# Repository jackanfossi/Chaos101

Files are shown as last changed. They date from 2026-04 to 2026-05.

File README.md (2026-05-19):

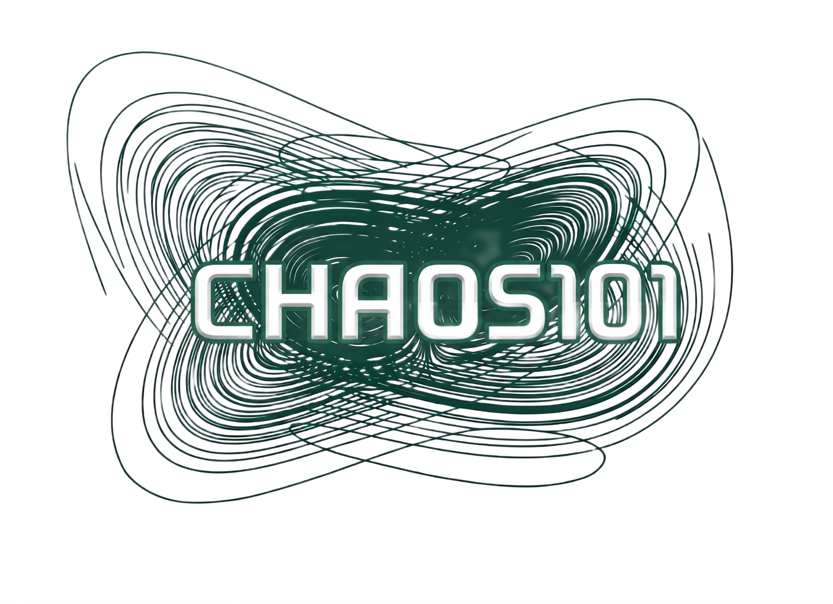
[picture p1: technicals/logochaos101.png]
#  Chaos 101

<p align="center">
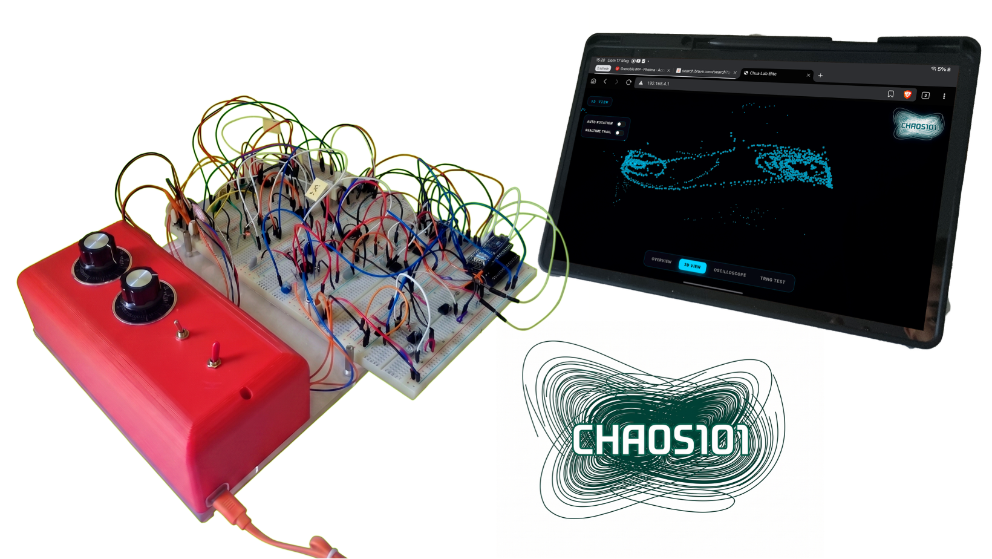
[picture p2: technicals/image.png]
Chaos 101 Ecosystem
  
</p>

Welcome to **Chaos 101**, an interactive project developed at **Grenoble INP - Phelma** to bridge the gap between abstract mathematics and physical reality.

We provide a tangible educational experience to explore how deterministic rules can lead to completely unpredictable behavior. Through our custom electronic circuit and Wi-Fi visualization system, you can discover the **"order hidden behind chaos"** and its vital role in modern technologies like secure data encryption.

---

## 🌀 Chaos for Everyone: An Intuitive Introduction
If you are new to this topic, here is a simple way to understand what we are working on:

### 1. Deterministic but Unpredictable
Usually, we think the world is either **predictable**, like planetary orbits, or **random**, like thermal fluctuations. Chaos is a special third category: it follows precise rules (it is deterministic), yet it turns out to be completely unpredictable over the long term.

### 2. The Butterfly Effect
The core of chaos is **extreme sensitivity to initial conditions**. If two identical chaotic systems start from states that differ by only a microscopic margin, their trajectories will eventually yield completely different outputs. This is why even a tiny change can lead to a massive difference later on.

### 3. Why is it useful? (TRNG)
Because chaos is so sensitive and unpredictable, it is perfect for creating **True Random Numbers**. While computers usually use predictable algorithms to create "random" numbers, our circuit uses the physical "messiness" of chaos to create sequences that are mathematically impossible to predict with precision. This makes digital encryption and cybersecurity much safer.

## 📂 Project Overview: What you will find
Based on our technical specifications, this repository provides a functional educational package that includes a real working device and the associated documentation. The goal is to provide an intuitive and visual comprehension of a chaotic system through an electronic circuit.

In this project, you will find:
* **Tangible Educational Device:** A portable and interactive hardware station designed for the general public.
* **Visualization System:** Direct monitoring of the system's evolution and display of the characteristic phase space diagrams, called attractors.
* **Wireless Communication:** A microcontroller interface using Wi-Fi protocol to allow for a simple setup and smartphone connection.
* **Practical Application (TRNG):** A demo of a True Random Number Generator to showcase the relevance of chaos theory in technology and security.
* **Autonomous Power Supply:** The entire system features an autonomous power supply to ensure maximum portability for events.
* **Open-Source Access:** Full technical documentation and a guide to set up the experience autonomously.
### Functional Diagram
<p align="center">
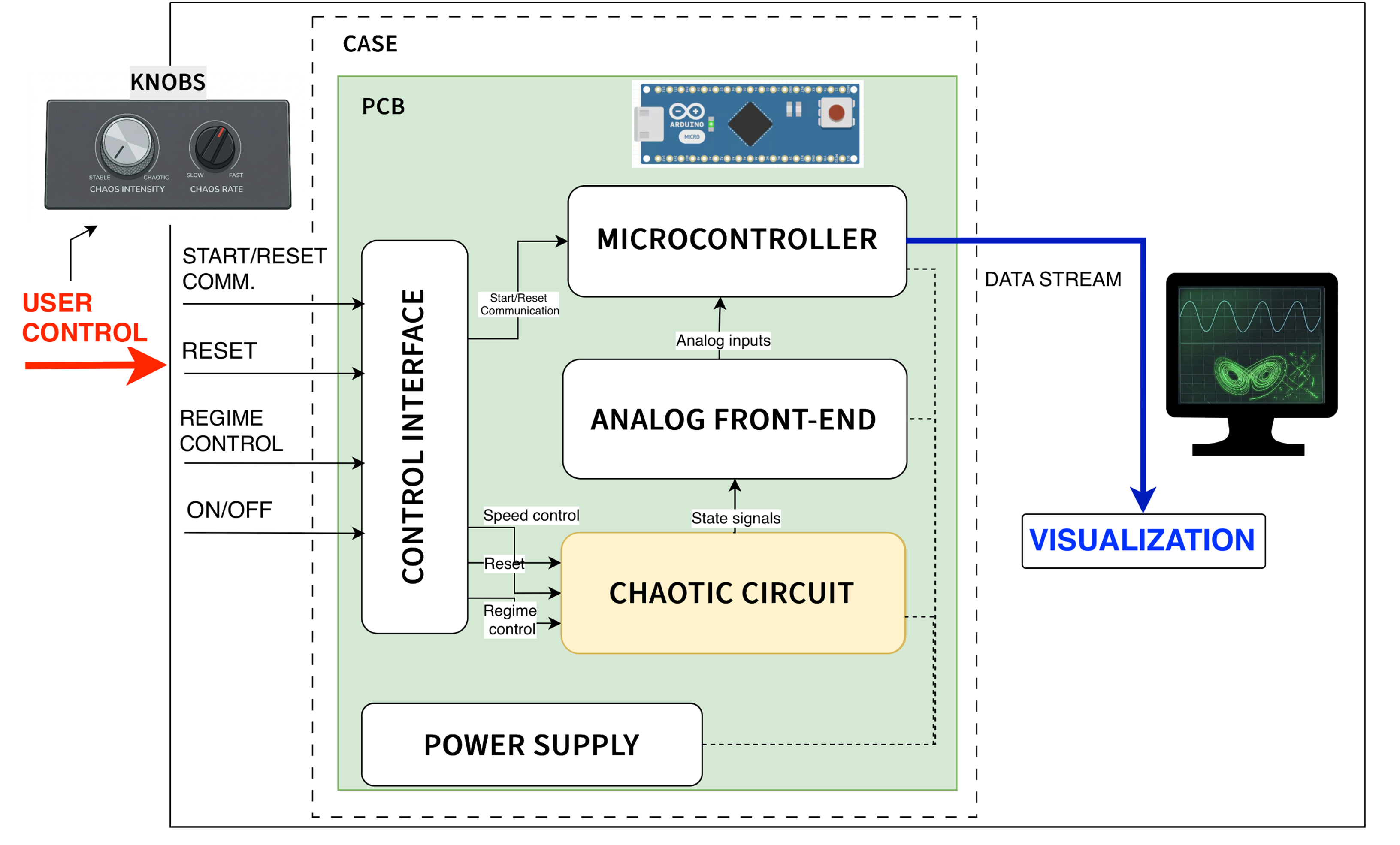
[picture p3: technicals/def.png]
Chaos 101 Functional Diagram
  
</p>

---

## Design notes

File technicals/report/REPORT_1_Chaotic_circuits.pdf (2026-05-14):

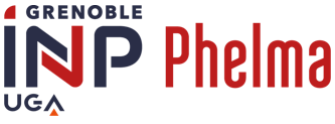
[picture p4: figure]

## Grenoble INP - Phelma MSc in Nanotechnologies Academic Year 2025 – 2026

# Chaos 101

## Project Phase 2: Specifications

## Team Members

Anfossi Giacomo | Jeljal Yanis
Bendin Andrea | Kovalchuk Anhelina
Fugnanesi Diana | Lanfranchi Tommaso
Gotas Matthieu | Tannenberg Finn

## Jalel Tasnim

## Tutors

## Prof. Davide Bucci Dr. Martial Defoort

May 14, 2026

Contents | Contents

# Contents

1 Excellence | 1
2 Impact | 5
3 Implementation | 7
References | 11

i

1. Excellence

# 1. Excellence

## 1.1. Objective

Introduction to chaos theory
It is common to think about the world as composed of two main types of systems. On the one hand, there are deterministic systems, such as a simple pendulum or planetary orbits. Their future states can be predicted with a high degree of accuracy once the governing laws and initial conditions are known. On the other hand, there are random systems, such as thermal fluctuations or the radioactive decay of an atom, which behave in an unpredictable manner and can only be described in terms of probability. Beyond these two main categories there is actually another class of systems whose evolution in time is perfectly described by some rules, meaning it is perfectly deterministic, yet turns out to be completely unpredictable over the long term: this is called chaos. This inherent unpredictability arises from the system’s extreme sensitivity to initial conditions. If two identical chaotic systems are initiated from states that differ by only a microscopic margin, their trajectories will eventually yield completely different outputs. This phenomenon is widely known as the butterfly effect, a concept first formally described by Edward Lorenz during his study of weather models in 1963 [1]. Since those foundational studies, chaos theory has developed over the decades. Researchers have identified and described chaotic dynamics in numerous natural and artificial systems, namely weather patterns, chemical reactions, lasers, fluid dynamics and electronic circuits [2]. Over time, chaos has also increasingly been studied with an engineering approach to be used for real-world technology. Several research fields are nowadays being explored, like cryptography and neuronal modeling [3, 4], but also concrete applications such as the True Random Number Generators (TRNGs) have emerged, making chaos theory a highly relevant field of study in contemporary technological research [5, 6] .

The electronic approach
In the context of chaos theory, electronic circuits are of huge interest. This branch of research has long explored the possibility of implementing chaotic behavior within electronic systems, starting with the pioneering work of Leon Chua [7]. The electrical domain is particularly advantageous because it provides a large degree of freedom for modelling differential equations and integrating non-linear components. Moreover, electronic circuits are robust, controllable, easily measurable, and characterized by a fast response time. For these reasons, chaotic circuits have been extensively studied and represent the main platform for investigating chaotic behaviour [8, 9].

The educational problem
Despite its prevalence in nature and engineering, chaos theory remains a challenging subject to comprehend and communicate, mainly due to the inherent difficulty in understanding and describing these complex, non-linear dynamics. Taught through abstract mathematical models, students and general audiences consistently struggle to visualize chaotic behavior and grasp its physical meaning. This significant educational gap leaves people largely unaware of what chaos is and how its principles apply to real applications and become useful.

Project objective
To address this significant educational gap, the absolute priority of this project is to build a tangible educational device easily understandable for the general public that aims to provide the answers of two fundamental questions: "What is chaos?" and "Why is it useful?" The project aims to provide an intuitive and visual comprehension of a chaotic system, through an electronic circuit exploiting its several advantages. The aim is to illustrate the fundamental properties of chaos and its behaviour, and to provide a direct demonstration of a concrete application. This device should be portable, affordable, interactive and the best alternative to traditional (and sometimes expensive) lab equipment.

Expected outcomes and target audience
The expected outcome of this project is to deliver a functional educational package that includes a real working device and the associated documentation. Moreover, it aims to reach a highly diverse audience. The primary intention is to engage people attending science fairs: non-experts, students, children, but also stimulate researchers. This educational package is also envisioned to be utilized in other educational channels, in particular high schools or universities, as a kit for laboratory activities. It might serve as an interesting lab project to spark curiosity or, even more, as a useful practical tool to study non-linear dynamical systems.

1. Excellence | 1.2. Concept

## 1.2. Concept

The project idea

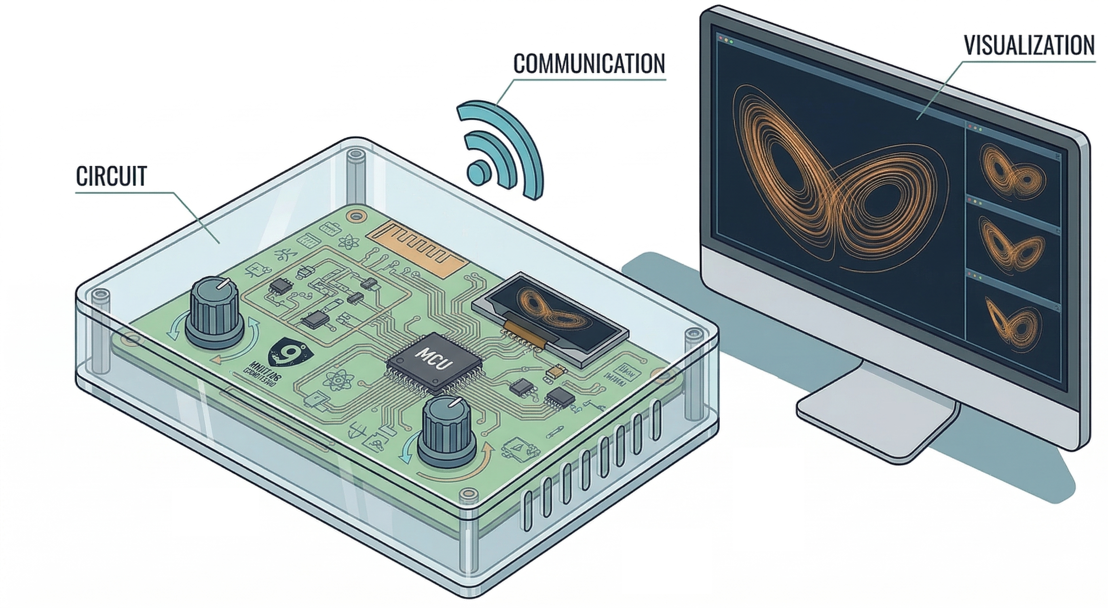
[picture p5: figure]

Figure 1: Project concept. Generated with AI Gemini

As presented, the goal of the project is to develop a device which will provide a laboratory experience related to chaotic systems. This device is based on a chaotic circuit, due to the numerous aforementioned advantages of working with electronics. Given its educational character, the name for this device and the entire project came naturally: CHAOS 101. The overall idea is to couple a visualization system to the chaotic circuit to display in real time its dynamical evolution and implement several features of interaction. The first question and the primary message to convey is “What is chaos?”. To tackle this, the main functions and features envisioned to be progressively implemented are:

1. Visualization system: direct monitoring of the system’s evolution and display of the characteristic phase space diagrams, called attractors. This is the most powerful aspect of the project, as it allows us to explain the order hidden behind chaos. It is envisioned to be developed through a microcontroller interface and wireless communication from the device to the visualization system. This allows for a simple setup procedure and opens the possibility of smartphone connection, which might be very useful for science fairs.
2. Transition from periodic dynamics to chaos: control over system parameters to transition from periodic to chaotic behavior. This allows for a hands-on experience where users can appreciate the transition and understand that it is something controllable and does not arise randomly.
3. Slowed-down evolution: system modifications to allow a slower evolution, demonstrating the phase space diagram formation and conveying a clear intuition of the unpredictable evolution.
4. Overlapping of trajectories: overlapping system trajectories with different initial conditions on the visualization, to show the sensitivity to initial conditions. This serves to convey the core concept of the definition of chaos.
5. Open-source access: an open-source repository to access all the useful material. The aim is to extend the project’s impact beyond the live presentation provided by the operator. This will include the full technical documentation and a guide to set up the experience, making CHAOS 101 accessible autonomously to everyone.

The second main question to address is "Why is it useful?" and for this the last feature to implement is:

6. Practical application: demo of a real application to transfer the relevance of chaos theory, in particular chaotic circuits, in technology and research.

Selection of the application
As previously mentioned, several research fields and concrete applications of chaos exist; thus, different options were analyzed to select the most suitable one. A significant technology in this context is the synchronization of multiple chaotic circuits. This phenomenon is the fundamental working principle of chaos-based encrypted communications, and it has also been widely studied as a physical model in biomedical engineering to simulate neuronal activity [10, 11, 12]. This is particularly relevant in medical research concerning Parkinson’s disease and the effects of Deep Brain Stimulation (DBS). However, the hardware implementation of synchronized circuits proved to be too elaborate within the scope of this project. Beyond the other applications, one revealed to be equally interesting and actually feasible: the True Random Number Generators.

1. Excellence | 1.3. Approach

Application: True Random Number Generator (TRNG)
TRNGs are a leading technology in the field of information security, where random number generation (RNG) is a key step to ensure high-security encryption. The TRNG represents the highest quality of RNG, performing over the widespread pseudo-RNG whose limitations are extensively known. The main feature of a TRNG is the coupling with a random physical process which guarantees a higher unpredictability. Common sources include thermal noise, phase jitter in oscillators, and also chaotic systems [6]. While the first two approaches are often affected by non-ideal circuit and environmental conditions, chaotic circuits are a perfect candidate for this application, leveraging on their nonperiodicity, broadband spectrum and their high sensitivity to initial conditions. The research is currently strongly focusing on optimizing chaotic TRNGs for ultra-compact, high-throughput hardware architectures, working on FPGAs and CMOS technologies [13]. Due to their superior energy efficiency, these modern chaotic generators are actively proposed for securing resource-constrained environments, such as Internet of Things (IoT) ecosystems, biomedical sensor networks, and edge computing devices[14].

## 1.3. Approach

Towards the technical implementation of the project several initial aspects need to be elaborated, in particular the feasibility assessment of hardware, TRNG implementation, communication plan and market analysis.

Feasibility assessment of hardware
A first investigation aims to select the most suitable chaotic circuit to implement. Specifically, the evaluation focuses on well-documented designs: the Chua’s circuit and its variants and the Sprott Jerk circuit [15, 16, 17]. The system of choice should balance manageable technical complexity with a high visual impact, allowing for the visualization and evolution of the "scenographic" shape of the attractor. The chaotic oscillators are evaluated based on their complexity, the availability of components in the university laboratory, and the shape of their phase space diagrams. Simulations are conducted using KiCAD and LTspice to gain familiarity before the physical implementation. This ensures that the chosen models are manageable and promising before moving to hardware implementation. After a comprehensive study of various chaotic oscillators, the selected circuits are tested in laboratory setup on the breadboard to validate the robustness of the design, the correct functioning, and reasonable controllability. Concerning the visualization the main interest is to develop a wireless communication between the hardware and the visualization. To this aim an interface using a microcontroller and Wifi protocol for the communication seems to be the most promising solution opening the possibility of smartphone connections. Initial testing is performed in the lab to assess its suitability.

TRNG implementation
To implement a reliable TRNG, the two main aspects to explore are the random number extraction and the validation tests. For the extraction, the main techniques that are considered are reported in Table 1. Concerning the validation, the methodology includes randomness and statistical testing. According to standards, the required validation test to be performed is the NIST suite [18]. However, in line with the pedagogical character of CHAOS 101, the testing is intended to be displayed in real-time. For this reason the full NIST is not feasible. Thus, alternative less formal tests have been identified, reported in Table 2.

A further idea is to show the superiority of the intrinsic entropy of hardware chaos with respect to the deterministic software algorithms used in pseudo-RNGs. To make this superiority tangible in terms of unpredictability and security, CHAOS 101 plans to showcase a side-by-side comparison between the circuit-generated sequence and a computergenerated one, highlighting how the proposed hardware system leverages sensitivity to initial conditions at a physical level so that even micro-environmental variations make the future sequence mathematically impossible to predict with precision, providing higher safety.

Extraction | Working Principle
ADC & LSB | Periodic sampling retaining only least signifi- cant bits [6].

Thresholding Analog comparison against a reference voltage
| to directly generate binary pulses [6].
Poincaré | Event-driven sampling triggered exclusively by specific state-space crossings [6].

Table 1: RNG strategies

Validation | Objective / Metric
Entropy | Evaluates information density [19].

χ

2
Test | Determines how much empirical distribution
| deviates from uniform [20].

Monte Carlo Spatial test mapping to (x, y); precision of
| π calculation depends on randomness qual-
| ity [20].
Table 2: Statistical tests for TRNG

1. Excellence | 1.4. Ambition

Communication plan
In order to showcase CHAOS 101 in a captivating and effective way, a communication plan will be developed. This will be designed for the audience to best experience chaos, considering not only what explanations to give, but also how to best convey them, for example, through direct interaction with CHAOS 101 or using a smartphone connection. To this end, a guide for the lab activity will be created, and these interactive aspects will be considered. In addition, other resources, such as posters to display during the events, may be produced. Furthermore, all documentation and materials will be carefully organized and shared through an open-source platform as a resource to autonomously develop the lab project.

Market Analysis
To validate the project’s assumptions regarding the general lack of awareness of chaos theory, an initial survey is going to be conducted targeting the general public, in particular students, and friends and relatives which still represents a good statistical set. The aim is to better solidify the relevance of the project.

## 1.4. Ambition

CHAOS 101 is not alone in the context of educational projects; there are already numerous useful resources available online. These have been analyzed, to identify where this project can bring significant improvements and distinguish itself from existing solutions.

Analysis of competitors
The most common methods to illustrate chaotic behavior can be broadly classified into two groups: purely digital simulations and purely physical systems. On the one hand, digital methods are simple to implement in classrooms and require little hardware, such as interactive simulations offered through websites or software tools like MATLAB or Python-based visualizations. They enable users to change system parameters and see the behavior that results in real time. These methods, however, don’t involve any real interaction. By using peripheral devices like a mouse or keyboard to abstract user input, the intuitive, physical understanding of the system is reduced.

On the other hand, physical demonstrations such as the Double Pendulum or a Magnetic Pendulum provide a direct, hands-on experience. These systems effectively illustrate sensitivity to initial conditions and are visually compelling. However, they are inherently limited in terms of controllability and parameter variation. Typically, the only form of interaction is the initial displacement, after which the system evolves autonomously.

Concerning electronic projects, several educational resources already exist covering all the different design circuits, Chua’s , Jerk’s, Lorentz’s to mention the most important. These contents provide documentation, tutorials, and video explanations, but these are generally self-contained in a website in the context of a "Do-It-Yourself" project and not widely available as a fully integrated, user-friendly educational device. They must be conducted in a lab setup, with costly instruments and they are not rapid and easy to assemble.

Envisaged innovation
CHAOS 101 aims to address all of these limitations. It aims to provide the double approach combining both physical interaction with dynamic parameter control. In contrast to purely mechanical systems, the circuit provides a way to adjust parameters, enabling transition from periodic to chaotic behavior.

In addition, compared to existing electronic projects, CHAOS 101 brings key innovations:

- Fully integrated physical interface, allowing for easy interaction with the circuit.
- Autonomous supply, making it a portable device
- Wireless data transmission system, allowing for simple setup and direct streaming of the state variables evolution into a web interface, eliminating the need for additional measurement tools such as an oscilloscope.
- Digital visualization opening numerous possibilities to share the resources with people rapidly and effectively.

Overall, it is worth noting that although the basic idea of an electronic chaotic circuit is not a new one, the contribution of this project lies in the integration of interactivity, accessibility, and modern connectivity. This makes the system particularly well-suited for educational and demonstrative purposes, where existing solutions either lack physical engagement or sufficient flexibility.

2. Impact

# 2. Impact

## 2.1. User Needs Analysis

To understand more precisely the impact and the relevance of CHAOS 101, a survey on chaos theory was shared with friends, students and relatives, who form a representative statistical set of the target audience. The goal was to assess the current level of awareness of the general public and bring foundation to this project. 93 answers were collected and the results are presented below.

## 2.2. Survey Results

The survey results reveal a generally limited familiarity with chaos theory.

Awareness and Knowledge Level

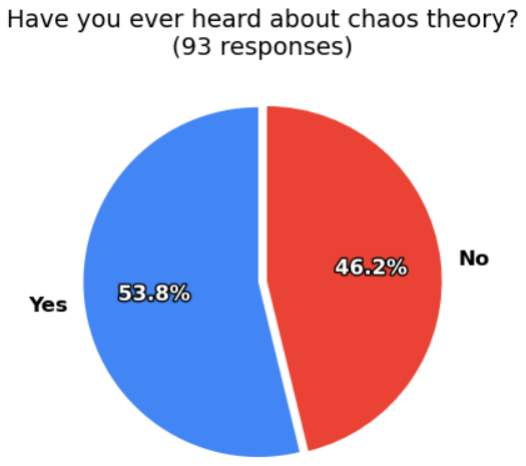
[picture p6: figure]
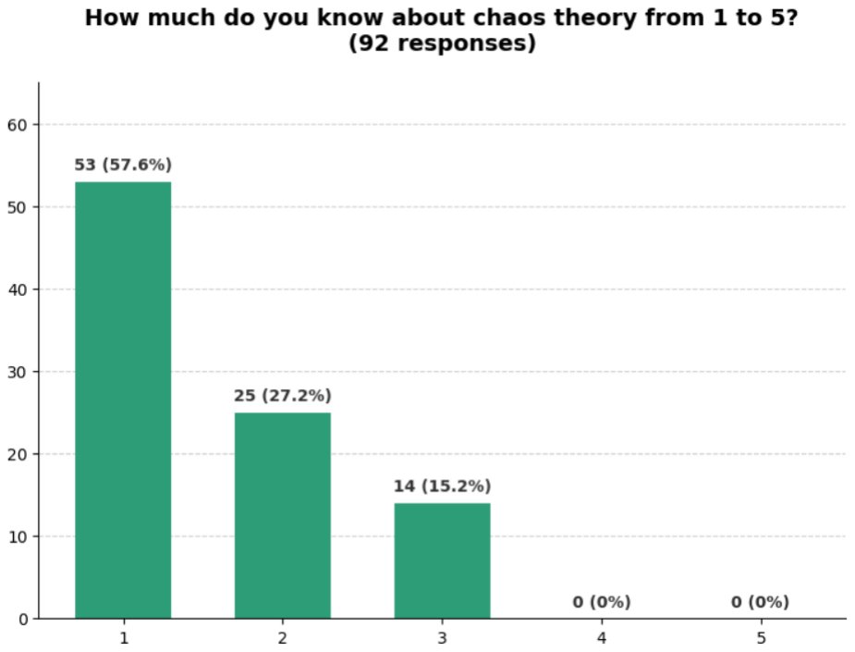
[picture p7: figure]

(a) Awareness of chaos theory | (b) Self-assessed knowledge level

Figure 2: General awareness and knowledge of chaos theory

As illustrated in Fig. 2a, more than half of the respondents (53.8%) reported having heard of chaos theory, while 46.2% had no prior exposure. However, awareness does not correspond to understanding. In fact, the majority of participants (57.6%) rated their knowledge at the lowest level (1 out of 5), while no respondents selected the highest levels, as shown in Fig. 2b. This shows that even among those who have heard of the term, the actual level of understanding is still very limited. This gap is likely due to the abstract nature of the topic, which is often introduced through mathematical formulations that are not easily accessible to a general audience.

Understanding and Perceived Applications

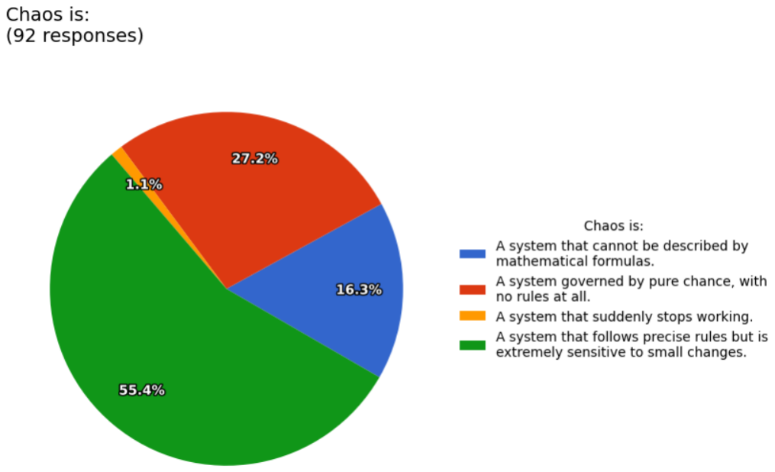
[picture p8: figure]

Figure 3: Definition of chaos

2. Impact | 2.3. Target Audience

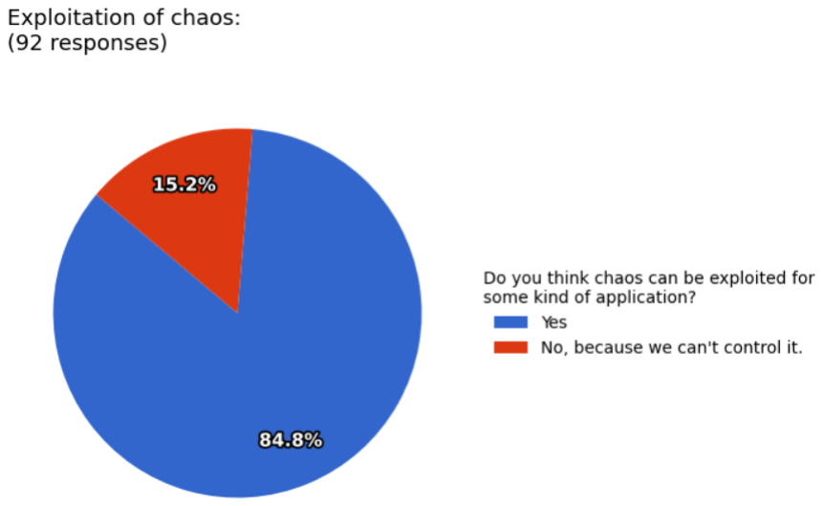
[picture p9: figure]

Figure 4: Perceived applications of chaos theory

As illustrated in the plot in Fig.3, when asked about the definition of chaos, only a portion of respondents correctly identified it as a deterministic system highly sensitive to initial conditions. A large number of participants instead associated chaos with randomness or unpredictability, highlighting several common misconceptions. Despite this limited understanding, a strong majority (84.8%) believe that chaos can have practical applications, as shown in the plot in Fig. 4. This suggests that people intuitively see that chaos is relevant in real-world phenomena, which could be used as a starting point for educational activities.

## 2.3. Target Audience

The project is designed for a broad and heterogeneous audience. Its primary target includes high school and undergraduate students, with limited exposure to advanced mathematical formalism, who can benefit from an intuitive and visual introduction to complex systems and chaos theory. Additionally, CHAOS 101 aims to reach a broader public of all ages, relying on the direct interaction, the visual impact and focusing the activity on a more basic level. The platform is also relevant for educators and science communicators, who may adopt it as a demonstrative tool to complement theoretical lessons with interactive experiences. Finally, CHAOS 101 also aims to stimulate researchers and highly qualified STEM professionals by showing concrete applications and highlighting the relevance of this research field.

## 2.4. Educational channels

Among the envisioned educational channels the main targets are science fairs and events; CHAOS 101 is intended as an assistive tool for researchers of this field to capture the attention of visitors and provide good communication. As already mentioned, this project is also intended to be used in schools and universities, as well as in museums and public exhibitions. Finally, internet is another relevant educational channel that will be utilized, particularly through an open-source platform, to reach the largest amount of people.

## 2.5. Market Positioning and Innovation Strategy

CHAOS 101 targets a growing niche market within the Educational Technology (EdTech) and science museum sectors. The main innovation is the shift from purely digital simulations to a tangible, hardware-based experience. While the physical implementation of the chaotic system is cost-effective and relatively simple, it offers clear advantages compared to existing software-based alternatives. For institutional users, such as schools and science festivals, the economic benefit is clear: a low-cost, durable device that provides a high-impact, "hands-on" learning experience. A key example of this added value is the integration of the Random Number Generator. By demonstrating a functional application in cybersecurity and data encryption, the exhibit is no longer just a visual demonstration, but also a practical proof-of-concept for real-world applications.

3. Implementation

# 3. Implementation

## 3.1. Project description

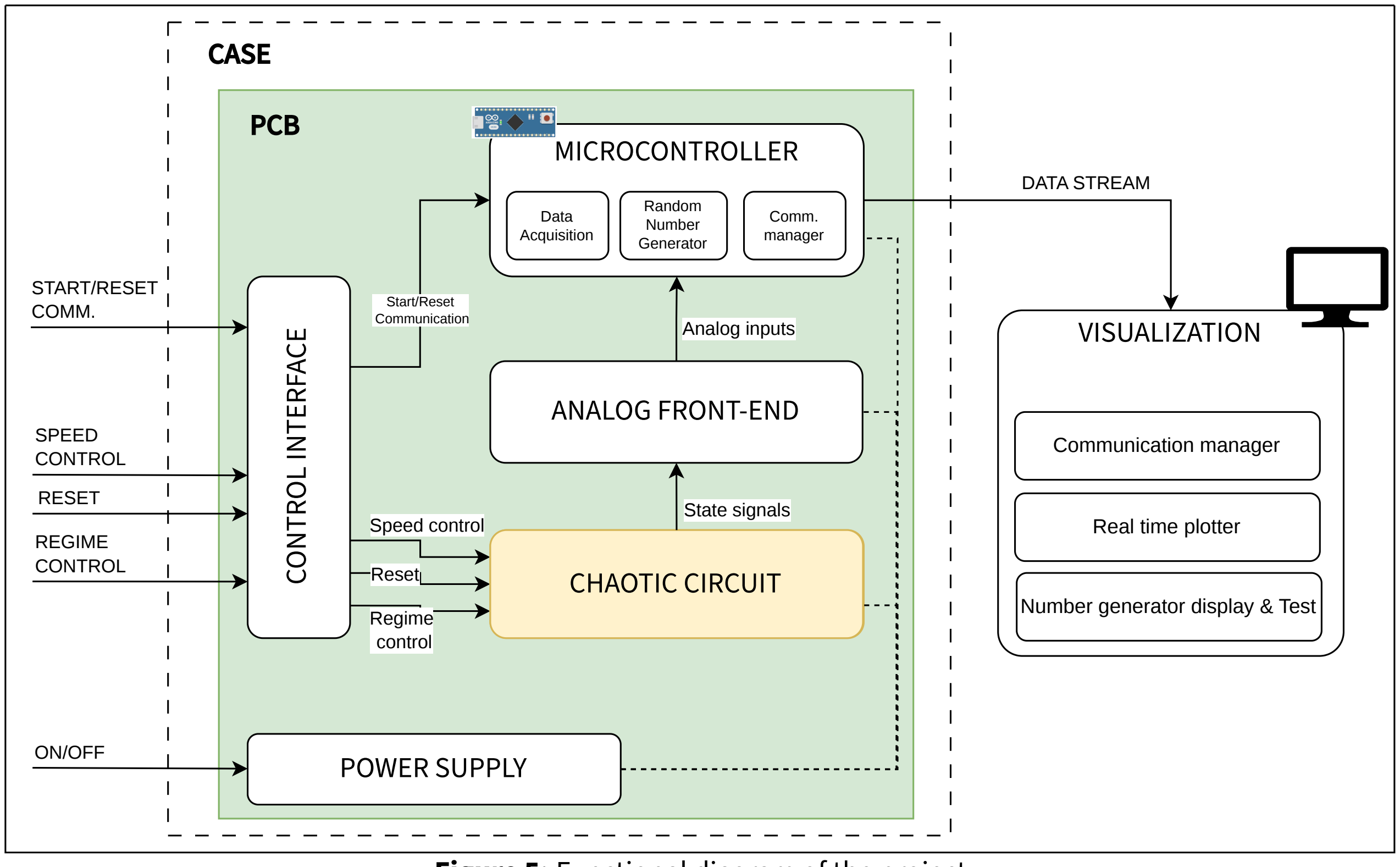
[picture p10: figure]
CASE; PCB PCB; Start/Reset Communication; Regime control; Reset; Speed control; POWER SUPPLY; MICROCONTROLLER; Data Acquisition; Random Number Generator; Comm. manager; CHAOTIC CIRCUIT; ANALOG FRONT-END; State signals; Analog inputs; REGIME CONTROL; RESET; SPEED CONTROL; VISUALIZATION; Communication manager; Real time plotter; Number generator display & Test; DATA STREAM; START/RESET COMM.; ON/OFF

Figure 5: Functional diagram of the project

A general description, shown in Figure 5, is presented regarding how the system is envisioned to be composed, along with the interaction of its main components. CHAOS 101 is composed of a hardware station that hosts the chaotic circuit and the electronic system to perform the readout. It features physical controls that allow the user to directly modify the circuit parameters and observe different dynamical regimes. The readout is handled with a microcontroller, which is properly interfaced to the circuit via an analog front-end. The microcontroller processes the acquired data, performs the random number generation and transmits everything to the visualization system using the most feasible communication protocol (unidirectional communication from micro to visualization). The visualization system then receives the data and produces the graphic display. The hardware station is implemented on a custom PCB and housed in a protective case. The entire system is also featured by an autonomous power supply to ensure maximum portability for the events.

## 3.2. Work packages definition

Based on the following structure, the development process is organized into distinct subtasks, referred to as Work Packages (WPs). The identified WP are presented in Table 3.

WP | Denomination
WP1 | Chaotic Circuit Development
WP2 | Analog Front End
WP3 | Firmware for Data Acquisition & Communication
WP4 | Visualization System
WP5 | Control functions
WP6 | Power Supply
WP7 | Random Number Generator
WP8 | PCB Design & Assembling
WP9 | Case Development
WP10 | Communication Plan & Branding

Table 3: List of Work Packages.

3. Implementation | | 3.3. Work packages description

## 3.3. Work packages description

The development process is structured into 10 distinct WPs, each with clearly defined objectives, deliverables and the team resources allocated.

- WP1: Chaotic Circuit Development Identification of the chaotic circuit to implement. It involves research in literature, identification of 3/4 circuits of interest followed by simulations using LTspice to study the dynamic and the setup parameters. Following these simulations, the breadboard implementation and physical validation are carried out.
Deliverable: Validated chaotic circuit schematic and assembled circuit onto the breadboard.
- WP2: Analog Front End Design, assembling and testing of the analog front end for output signal conditioning from the chaotic circuit to the microcontroller.
Deliverable: Circuit schematic and assembled circuit on the breadboard
- WP3: Firmware for Data Acquisition and Communication. Selection of an appropriate microcontroller, and firmware implementation, in particular reading of analog inputs, data processing, and real-time data streaming to the visualization system.
Deliverables: Firmware code
- WP4: Visualization System. Development of a local web interface designed to receive data from the microcontroller and plot the chaotic attractors in real-time, offering multiple visualization options for the audience. Deliverables: Web interface source code
- WP5: Control functions . Developing the user interface for physical interaction with the chaotic circuit. It includes integrating variable potentiometers, capacitors to slow down the signal, and control switches. Deliverables: updated circuit schematics integrating user controls and updated circuit on breadboard.
- WP6: Power Supply. This task is dedicated to designing an autonomous power supply system, including battery selection and the implementation of appropriate voltage converters for the microcontroller and operational amplifiers.
Deliverables: Power supply schematic, selected battery specifications and additional components.
- WP7: Random Number Generator. Theoretical development and practical implementation of the True Random Number Generator. Design of number extraction at the firmware/hardware level and display features on the visualization system.
Deliverables: updated microcontroller firmware/circuit schematic and updated web interface source code
- WP8: PCB Design & assembling. Transferring of the validated schematic circuit, fully tested on breadboard, into a permanent, robust PCB design. Assembling of the PCB and testing, design reiteration if needed. Deliverables: Fully printed, assembled, and functional PCB.
- WP9: Case Integration. Designing and manufacturing of the custom housing for the PCB to ensure safety, robustness portability, and a professional appearance.
Deliverables: Designed and 3D-printed enclosure.
- WP10: Communication Plan & Branding. Educational strategy, ensuring the final product effectively communicates chaos theory to the public. It includes defining the visitor experience and creating accessible documentation to share, identify a proper open source platform and share the material.
Deliverables: Support resources for CHAOS 101 and online upload of materials.
WP | Work Package Name | Responsible members
WP1 | Chaotic Circuit Development | Giacomo, Finn, Tasnim, Yanis, Matthieu, Diana, Tommaso
WP2 | Analog Front End | Matthieu, Tasnim
WP3 | Firmware | Anhelina
WP4 | Visualization System | Anhelina, Andrea
WP5 | Control functions | Yanis, Giacomo
WP6 | Power Supply | Finn
WP7 | Random Number Generator | Tommaso, Diana
WP8 | PCB Design & assembling | Yanis, Matthieu
WP9 | Case Integration | Andrea
WP10 | Communication Plan & Branding | Giacomo, Tommaso, Diana, Tasnim

Table 4: List of Work Packages.

3. Implementation | 3.4. Work timeline

## 3.4. Work timeline

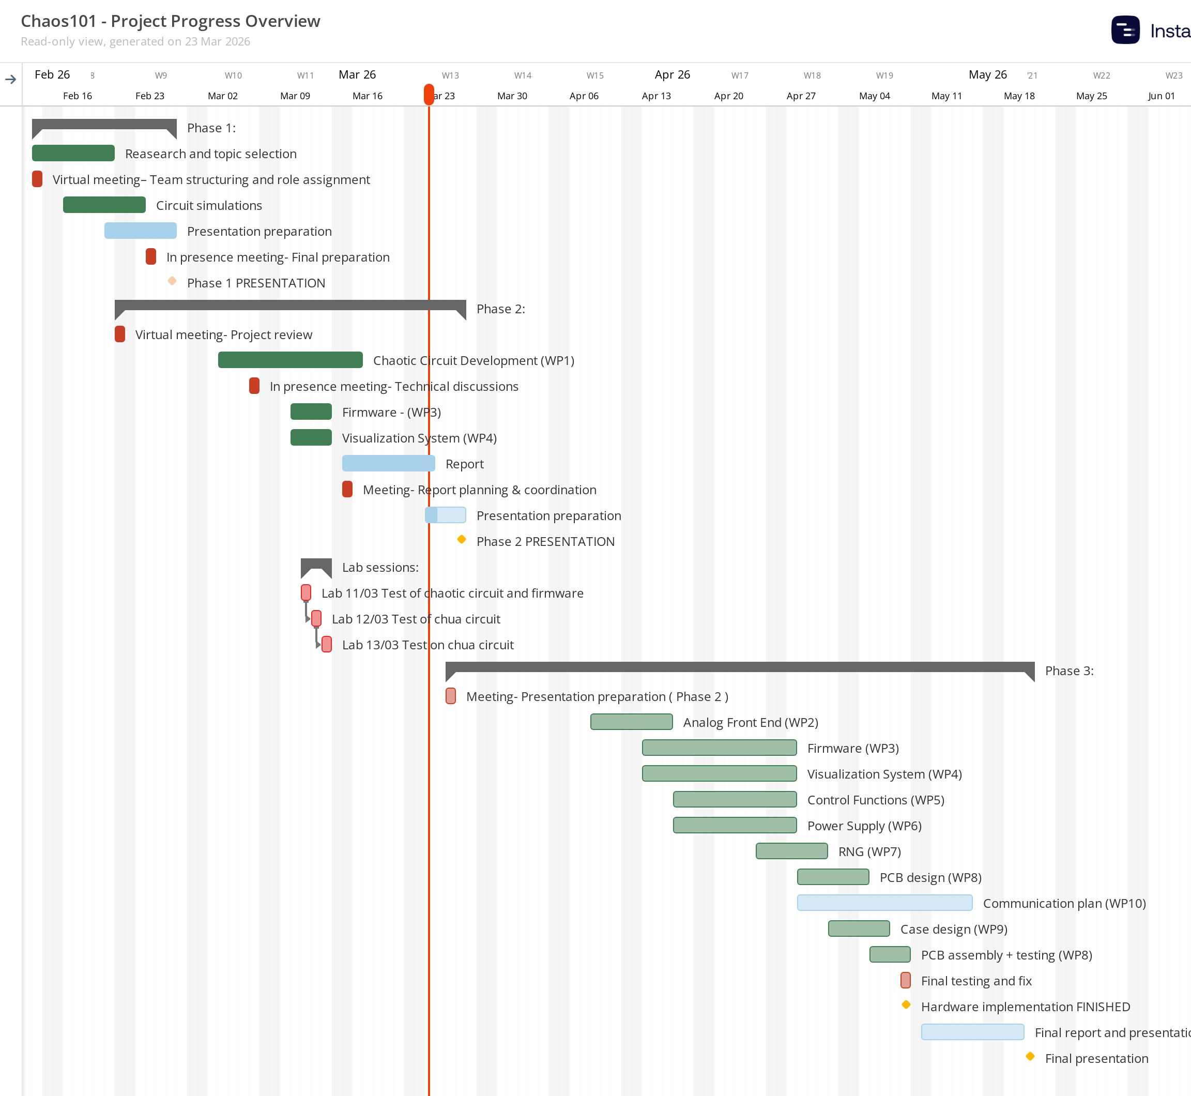
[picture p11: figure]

Figure 6: Gantt diagram of CHAOS 101 realized on Instagantt. Resource available online [21].

The project work is divided into three main phases: the preparation phase, the specification phase (currently ongoing), and the development phase. The key milestones that dictate the project’s evolution are the presentations scheduled for:

- PHASE 1: February 26 – State of the Art: Bibliographic study, physical principles, and context.
- PHASE 2: March 26 – Specifications: Building blocks, project scheduling, and market.
- PHASE 3: May 19 – Development: Technical achievements, final report, and discussion.

The work involves laboratory sessions, the scheduling of which is critical for progress. In Phase 2, laboratory sessions were carried out for the feasibility assessment and development of the chaotic circuit (WP1). In the upcoming development phase, the work packages have been allocated appropriate timeframes, and subsequent laboratory sessions will be scheduled for them. Work packages WP3 through WP6 will be carried out in parallel to maximize teamwork and efficiency.

Remark on Meetings Organization It is important to note that weekly meetings are not systematically planned in advance. Due to the collaborative nature of the project, frequent informal discussions take place among team members, with or without the tutor present, often during breaks or working sessions. Formal meetings are organized only when necessary, particularly at key stages of the project, such as for decision-making, progress evaluation, or the preparation of deliverables. This flexible approach allows the team to maximize the effectiveness of meetings.

3. Implementation | 3.5. Management structure and procedures

## 3.5. Management structure and procedures

The management structure of CHAOS 101is designed to be highly collaborative and agile. Rather than operating under a rigid hierarchy, for the crucial choices the team relies on a democratic decision-making process, thanks to the active contribution of each member. This structure ensures all team members are aligned and, more importantly, invested in the outcome. To ensure smooth progress, the specific decisions involved in the development are taken by the team members responsible of the work. For the internal communication, the team holds frequent coordination meetings, utilizing both in-person sessions and video conferencing.

While the team operates horizontally, one member actively assumes the role of a manager. This role involves maintaining an updated overview of the project, managing work divisions and internal communication, tracking task completion across different work packages, and ensuring that deadlines are met without overriding the democratic consensus of the group on last minute decisions. Furthermore, the team is split into 3 subdivisions: electronics, research, software as shown in Figure 7. This ensures clear subdivision of responsibilities; however, a strong flexibility is required to fulfil the various tasks, especially in light of project presentations, specifically, drafting reports, and conducting theoretical research.

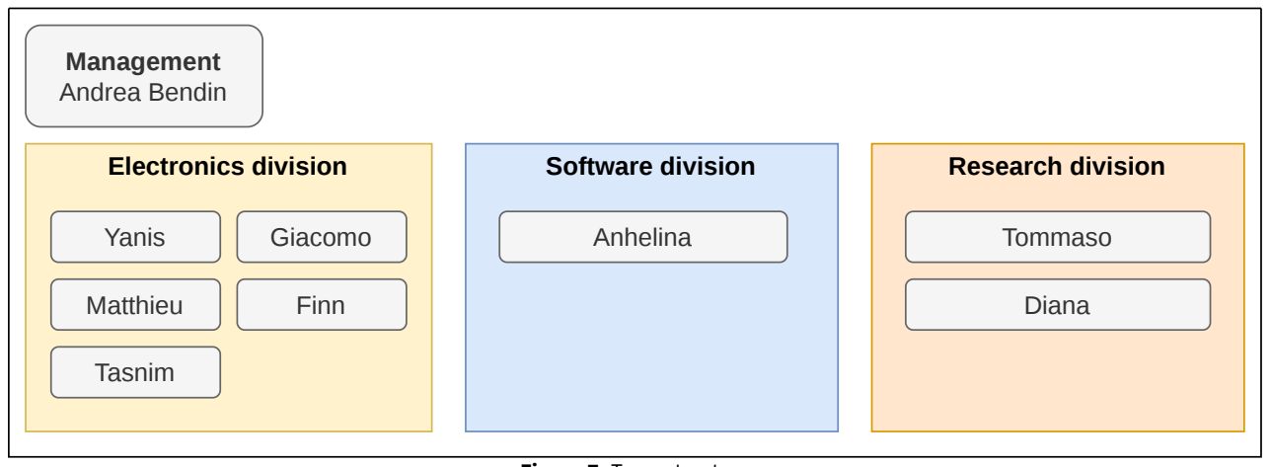
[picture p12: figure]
Yanis; Matthieu; Tasnim; Anhelina; Tommaso; Diana; Giacomo; Finn; Management Andrea Bendin

Electronics division | Software division | Research division

Figure 7: Team structure

## 3.6. Consortium as a whole

The consortium consists of nine dedicated members who possess a diverse and complementary skill set, allowing for an effective division of labor across specialized sub-groups while maintaining strong overall cohesion.

Yanis, Tasnim, and Matthieu possess relevant skills in PCB design and electronic assembly; therefore, they are responsible for the electronic development, supported by Giacomo, physics engineer, and Finn, electronic engineer, in the assembly and testing phases. Anhelina, biomedical engineer, having previous expertise in embedded system programming, is responsible for the firmware and the visualization system. Diana, physics engineer, and Tommaso, physicist, are in charge of the RNG implementation, leveraging their analytical and technical skills. Andrea, with experience in electronic and mechanical design, acts as the project manager, supervising the overall work of the subdivisions and designing the case.

Division | Member | Expertise

Electronic

| Jeljal Yanis | Electronics, PCB design
| Gotas Matthieu | Electronics, PCB design.
| Jalel Tasnim | Electronics, PCB design.
| Tannenberg Finn | Electronics, Optics
| Anfossi Giacomo | Physics, research analysis, electronics.
Research | Lanfranchi Tommaso | Theoretical physics
| Fugnanesi Diana | Physics, electronics.
Software | Kovalchuk Anhelina | Telecommunications, software development.
Management | Bendin Andrea | Electronics, mechanical design.

Table 5: Consortium members grouped by operational division and specialized expertise.

References | References

# References

[1] Edward N. Lorenz. “Deterministic nonperiodic flow”. In: Journal of the Atmospheric Sciences 20.2 (1963), pp. 130–141. DOI: 10.1175/1520-0469(1963)020<0130:DNF>2.0.CO;2. (https://doi.org/10.1175/1520-0469(1963)020<0130:DNF>2.0.CO;2)
[2] Steven H. Strogatz. Nonlinear Dynamics and Chaos: With Applications to Physics, Biology, Chemistry, and Engineering. 2nd ed. Boca Raton, FL: CRC Press, 2015. DOI: 10.1201/9780429492563. (https://doi.org/10.1201/9780429492563)
[3] Ljupčo Kocarev. “Chaos-based cryptography: a brief overview”. In: IEEE Circuits and Systems Magazine 1.3 (2001), pp. 6–21. DOI: 10.1109/7384.963463. (https://doi.org/10.1109/7384.963463)
[4] Kazuyuki Aihara, Teruya Takabe, and Masataka Toyoda. “Chaotic neural networks”. In: Physics Letters A 144.6-7 (1990), pp. 333–340. DOI: 10.1016/0375-9601(90)90136-C. (https://doi.org/10.1016/0375-9601(90)90136-C)
[5] Müştak E Yalçın, Johan AK Suykens, and Joos Vandewalle. “True random bit generation from a double-scroll attractor”. In: IEEE Transactions on Circuits and Systems I: Regular Papers 51.7 (2004), pp. 1395–1404. DOI: 10.1109/TCSI.2004.830683. (https://doi.org/10.1109/TCSI.2004.830683)
[6] Fei Yu et al. “A survey on true random number generators based on chaos”. In: Discrete Dynamics in Nature and Society 2019.1 (2019), p. 2545123. DOI: 10.1155/2019/2545123. (https://doi.org/10.1155/2019/2545123)
[7] Leon O Chua. “The genesis of Chua’s circuit”. In: AEU-Archiv für Elektronik und Übertragungstechnik 46.4 (1992), pp. 250–257.
[8] Jiří Petržela. “Chaos in Analog Electronic Circuits: Comprehensive Review, Solved Problems, Open Topics and Small Example”. In: Mathematics 10.22 (2022), p. 4381. DOI: 10.3390/math10224381. (https://doi.org/10.3390/math10224381)
[9] Leon O Chua. Chua’s Circuit: A Paradigm for Chaos. Singapore: World Scientific, 1993. DOI: 10.1142/2005. (https://doi.org/10.1142/2005)
[10] Louis M. Pecora and Thomas L. Carroll. “Synchronization in chaotic systems”. In: Physical Review Letters 64.8 (1990), pp. 821–824. DOI: 10.1103/PhysRevLett.64.821. (https://doi.org/10.1103/PhysRevLett.64.821)
[11] Stefano Boccaletti et al. “The control of chaos: theory and applications”. In: Physics reports 329.3 (2000), pp. 103–197. DOI: 10.1016/S0370-1573(99)00096-4. (https://doi.org/10.1016/S0370-1573(99)00096-4)
[12] James L. Hindmarsh and R. M. Rose. “A model of neuronal bursting using three coupled first order differential equations”. In: Proceedings of the Royal Society of London. Series B. Biological Sciences 221.1222 (1984), pp. 87–102. DOI: 10.1098/rspb.1984.0024. (https://doi.org/10.1098/rspb.1984.0024)
[13] Liang Yao, Peiyang Kang, Deqin Shi, et al. “IRCA-TRNG: A Lightweight Dual-Ring Chaotic TRNG With Perturbation Refresh for High Throughput”. In: IEEE Transactions on Very Large Scale Integration (VLSI) Systems 33.12 (2025), pp. 3329–3340.
[14] Min-Kyu Kim et al. “A 82-nW chaotic map true random number generator based on a sub-ranging SAR ADC”. In: IEEE Journal of Solid-State Circuits 52.7 (2017), pp. 1953–1965. DOI: 10.1109/JSSC.2017.2690875. (https://doi.org/10.1109/JSSC.2017.2690875)
[15] Davide Bucci. Playing with chaos - Le circuit de Chua. 2016. URL: http://davbucci.chez-alice.fr/index.php?argument=elettronica/chua/chua.inc (http://davbucci.chez-alice.fr/index.php?argument=elettronica/chua/chua.inc) (visited on 03/24/2026).
[16] Arturo Buscarino et al. A Concise Guide to Chaotic Electronic Circuits. Springer International Publishing, 2014. DOI: 10.1007/978-3-319-05900-6. (https://doi.org/10.1007/978-3-319-05900-6) URL: https://link.springer.com/book/10.1007/978-3-319-05900-6. (https://link.springer.com/book/10.1007/978-3-319-05900-6)
[17] ChuaCircuits.com. How to Build Chua’s Circuit. 2023. URL: https://chuacircuits.com/how-to-buildchuas-circuit-1/ (https://chuacircuits.com/how-to-build-chuas-circuit-1/) (visited on 03/24/2026).
[18] Andrew Rukhin et al. A statistical test suite for random and pseudorandom number generators for cryptographic applications. Tech. rep. Gaithersburg, MD, USA: National Institute of Standards and Technology (NIST), 2010. DOI: 10.6028/NIST.SP.800-22r1a. (https://doi.org/10.6028/NIST.SP.800-22r1a)
[19] Claude E Shannon. “A mathematical theory of communication”. In: The Bell System Technical Journal 27.3 (1948), pp. 379–423. DOI: 10.1002/j.1538-7305.1948.tb01338.x. (https://doi.org/10.1002/j.1538-7305.1948.tb01338.x)
[20] Athanasios Papoulis and S. Unnikrishna Pillai. Probability, Random Variables, and Stochastic Processes. 4th ed. McGraw-Hill, 2002.
[21] Instagantt. Project Schedule - Shared Gantt Chart. 2026. URL: https://app.instagantt.com/shared/s/D4HnvHKLigN9Yy3oHeY3/latest (https://app.instagantt.com/shared/s/D4HnvHKLigN9Yy3oHeY3/latest) (visited on 03/23/2026).

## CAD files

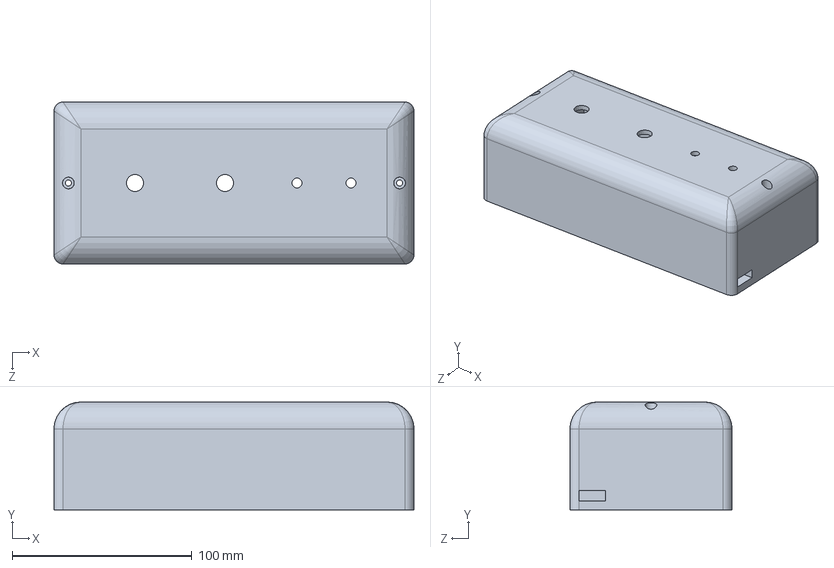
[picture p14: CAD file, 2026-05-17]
technicals/Chaos101_tech/Case.SLDPRT
200.0 x 60.0 x 90.0 mm

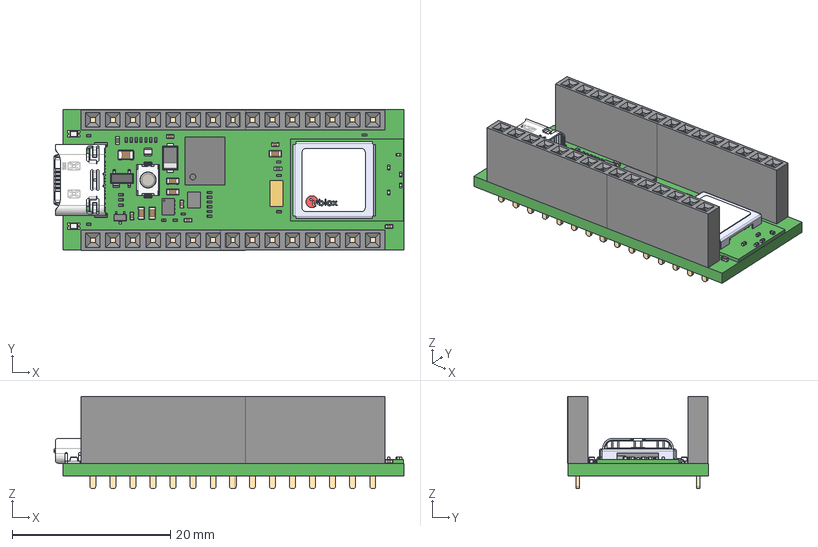
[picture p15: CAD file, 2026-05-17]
technicals/Chaos101_v14/Librairies/03-Modeles3D/NANO_ESP32.step
44.3 x 17.8 x 11.7 mm
RES-0201 x 21
CAP-0402 x 6
Extruded x 90
CAP-0201 x 4
pins
logo
label_8x8
logo_x_4mm
logo_o_4mm
logo_l_4mm
logo_b_4mm
logo_u_4mm
MAYA_W1_Shield_UBXH04-0000683
RES-0402 x 2
Thermal_Shape
SOT-523
HSMx-190 x 2
CAP-0603 x 5
lead x 2
SMLP34RGB
Header _Fem_1X8 x 4
PTS820J20KSMTRLFS
CX90B-16P_3D
PRTR5V0U2X
CAP-0805

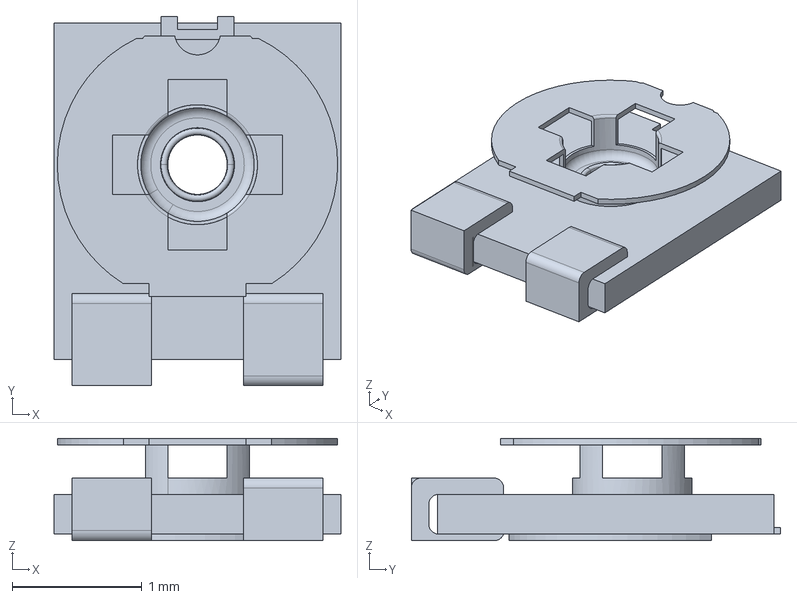
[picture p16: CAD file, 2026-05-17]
technicals/Chaos101_v14/Librairies/03-Modeles3D/TC42.stp
2.21 x 2.84 x 0.787 mm

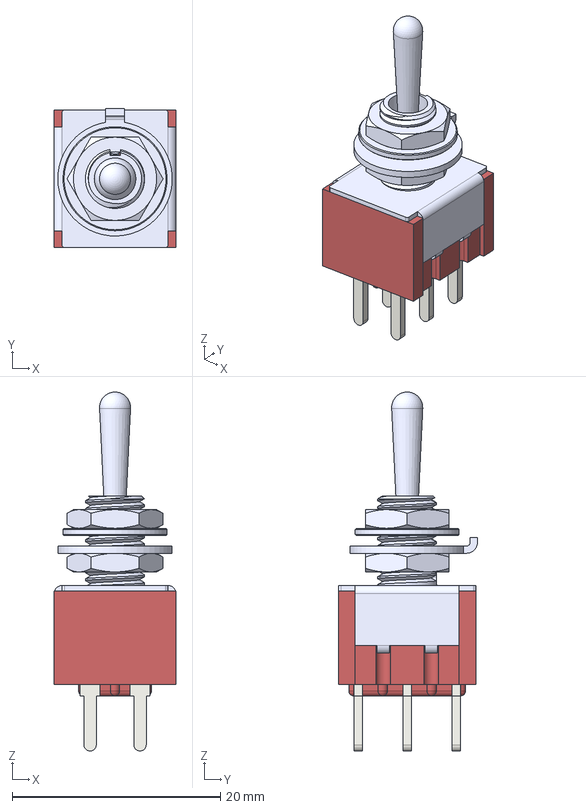
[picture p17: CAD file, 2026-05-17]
technicals/Chaos101_tech/Toggle_Switch_DPDT_PCB.step
11.7 x 13.4 x 34.5 mm
Washer Anti Twist Protection
Nut M6x0.75mm
Nut M6x0.75mm clone
Fantastic Plastic Body
Neck
Washer
PCB PIN 01
PCB PIN clone 02
PCB PIN clone 03
PCB PIN clone 04
PCB PIN clone 05
PCB PIN clone 06
Sheetmatal Frame
Font O 001
Font N 001
Font - 001
Font O 002
Font F 001
Font F 002
Font - 002
Font O 003
Font N 002
Batton

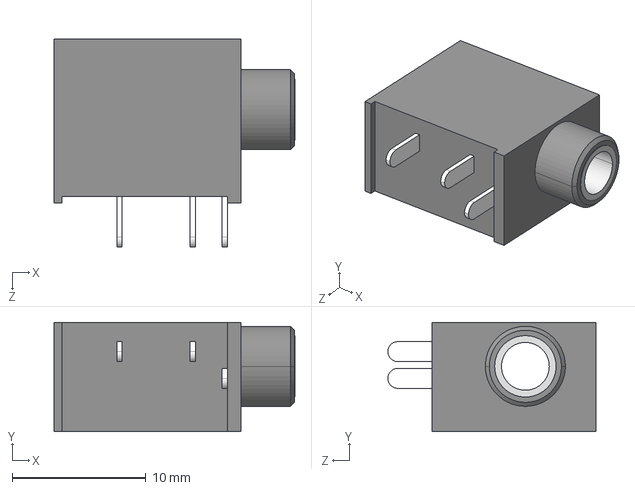
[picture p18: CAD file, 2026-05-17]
technicals/Chaos101_v14/Librairies/03-Modeles3D/CUI_DEVICES_SJ1-3533NG.step
18.1 x 8.20 x 15.6 mm

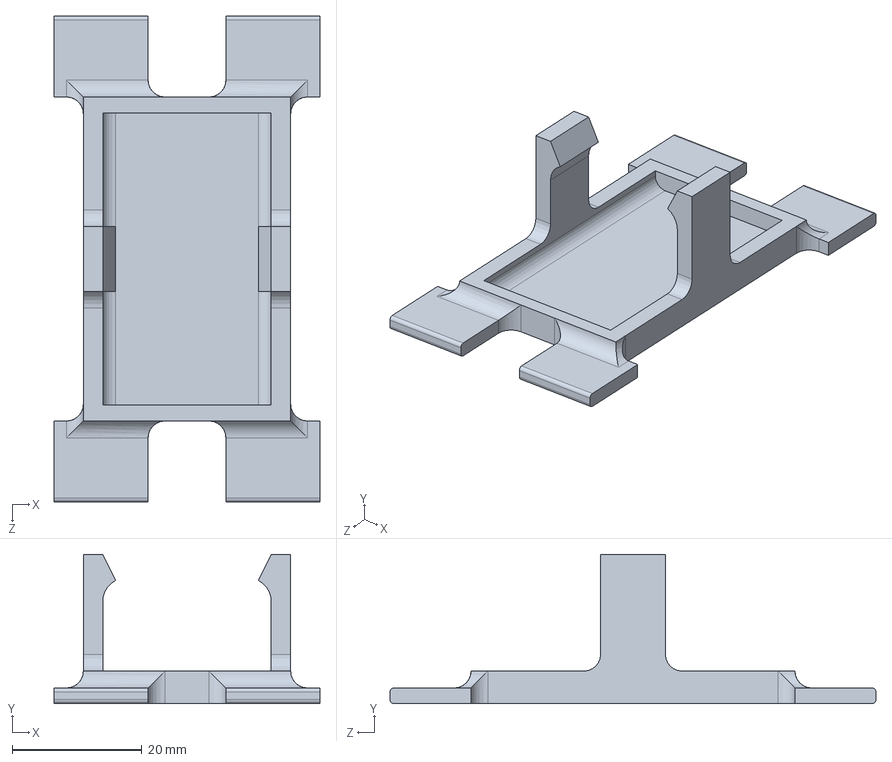
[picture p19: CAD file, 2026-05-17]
technicals/Chaos101_tech/Battery_Holder.SLDPRT
41.0 x 23.0 x 75.0 mm

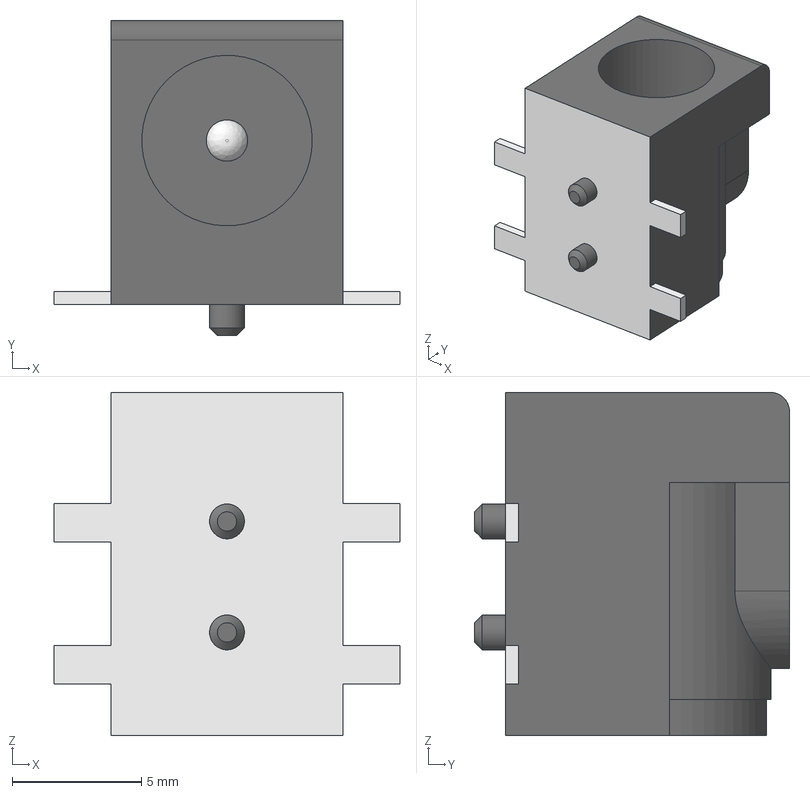
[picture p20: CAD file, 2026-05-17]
technicals/Chaos101_v14/Librairies/03-Modeles3D/BarrelJackSMD v3.step
13.4 x 12.2 x 13.3 mm

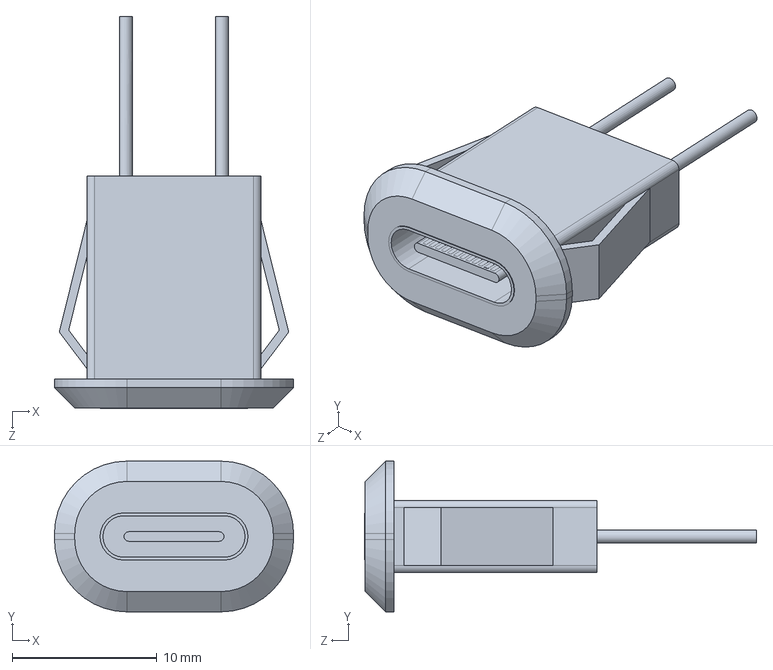
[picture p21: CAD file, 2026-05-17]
technicals/Chaos101_tech/USB-Port.SLDPRT
16.5 x 10.4 x 27.1 mm

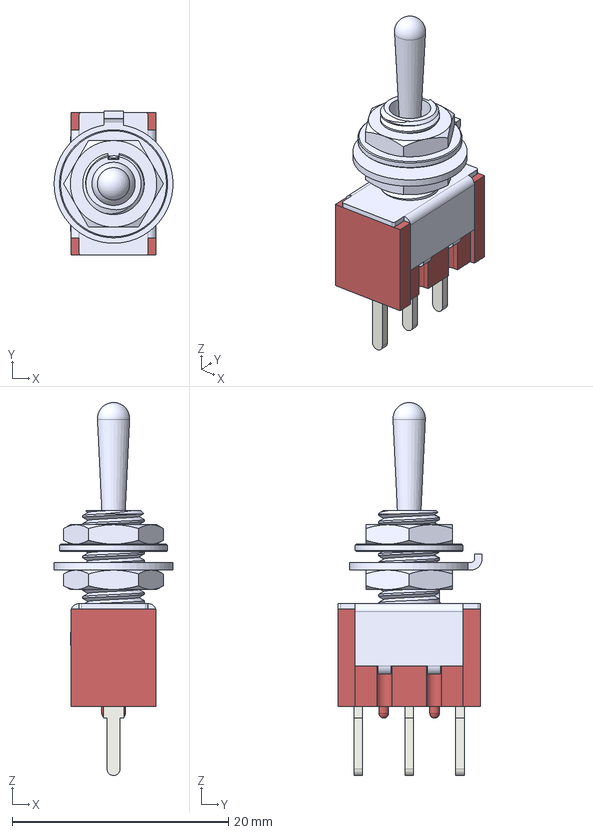
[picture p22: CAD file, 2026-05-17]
technicals/Chaos101_tech/Toggle_Switch_SPDT_PCB.step
11.0 x 13.4 x 34.5 mm
Washer Anti Twist Protection001
Nut M6x0.75mm 001
Nut M6x0.75mm clone001
Fantastic Plastic Body001
Neck001
Washer001
PCB PIN 002
PCB PIN clone 007
PCB PIN clone 008
Sheetmatal Frame001
Font O 004
Font N 003
Font - 003
Font O 005
Font F 003
Font F 004
Font - 004
Font O 006
Font N 004
Batton001

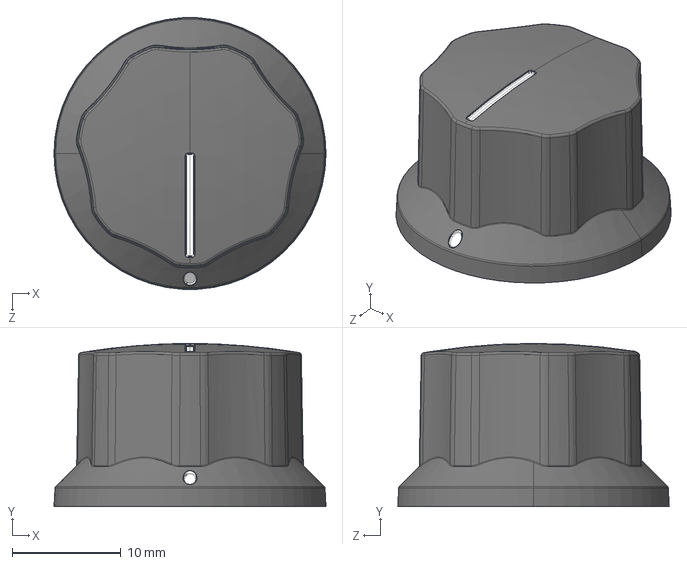
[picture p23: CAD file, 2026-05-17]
technicals/Chaos101_tech/MXR_ECB130_KNOB.STEP
25.0 x 15.0 x 25.0 mm

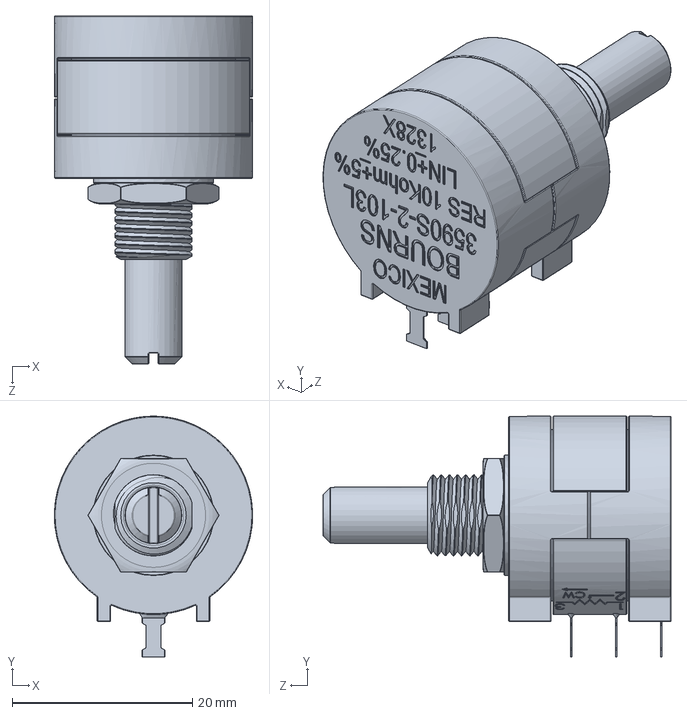
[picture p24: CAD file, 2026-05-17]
technicals/Chaos101_tech/multi turn.SLDPRT
22.0 x 26.7 x 38.6 mm

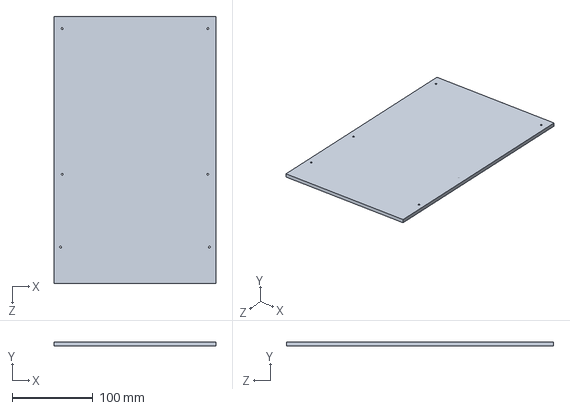
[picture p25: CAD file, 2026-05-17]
technicals/Chaos101_tech/Plate.SLDPRT
200.0 x 5.00 x 330.0 mm

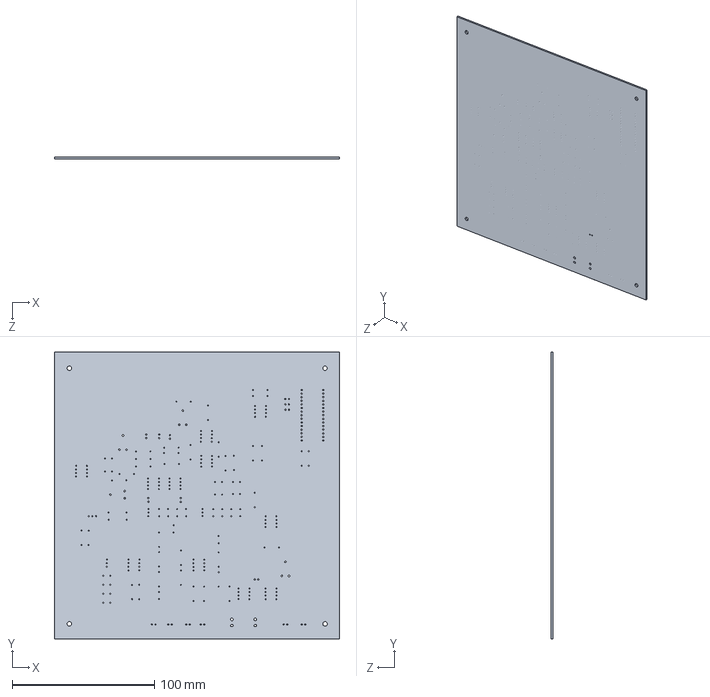
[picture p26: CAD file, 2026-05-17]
technicals/Chaos101_tech/PCB.SLDPRT
200.7 x 201.9 x 1.51 mm

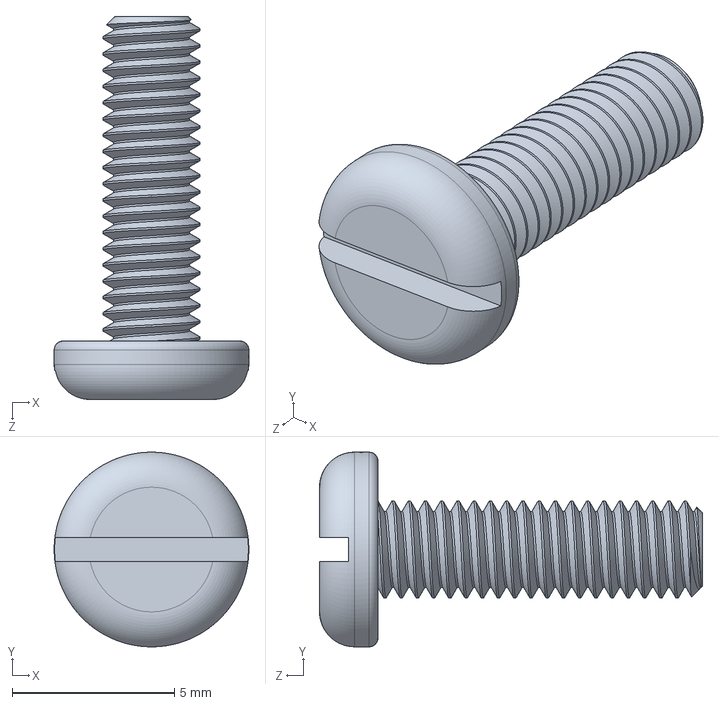
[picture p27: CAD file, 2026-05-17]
technicals/Chaos101_tech/91200A116_18-8 Stainless Steel Pan Head Slotted Screws.SLDPRT
6.00 x 6.00 x 11.8 mm

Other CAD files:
technicals/Chaos101_tech/Chaos101.SLDASM
technicals/Chaos101_tech/91920A570_Female Threaded Hex Standoff.SLDPRT
technicals/Chaos101_tech/94868A722_Female Threaded Hex Standoff(1).SLDPRT
technicals/Chaos101_tech/9v Duracell Battery Wyatt Sanders.ipt

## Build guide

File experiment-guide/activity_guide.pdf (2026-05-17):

CHAOS 101 — Activity Guide | Grenoble INP-Phelma · MSc Nanotechnologies

# CHAOS 101

## Activity Guide

G. Anfossi, A. Bendin, D. Fugnanesi, M. Gotas, T. Jalel, Y. Jeljal, A.
| Kovalchuk, T. Lanfranchi, F. Tannenberg

## 1. Introduction to Chaos

### What is chaos?

Chaos bridges the gap between order and randomness. It is deterministic yet unpredictable: while it follows exact mathematical laws, its long-term behavior remains impossible to forecast.

It is not randomness — it is extreme sensitivity to initial conditions.

### Applications and Importance of Chaos

Why study chaos?

- Understanding Natural Systems: From weather forecasting to stock market dynamics.
- Cryptography and Security: Utilizing extreme sensitivity to initial conditions to generate secure keys.
- Biomedical Engineering: Analyzing cardiac rhythms and brain activity patterns.

In our circuit, chaos enables TRNG by leveraging physical unpredictability over predictable algorithms. This ensures mathematically unpredictable sequences, greatly enhancing digital encryption and cybersecurity.

### The Chua’s circuit

This specific circuit was selected because it offers the simplest and most effective way to easily integrate and modulate complex chaotic behaviors in hardware..

Why Chua’s circuit?

- Simplest system for real chaos
- Fully op-amp based (TL082)
- Iconic double-scroll attractor

## 2. The Device Interface

### The Hardware

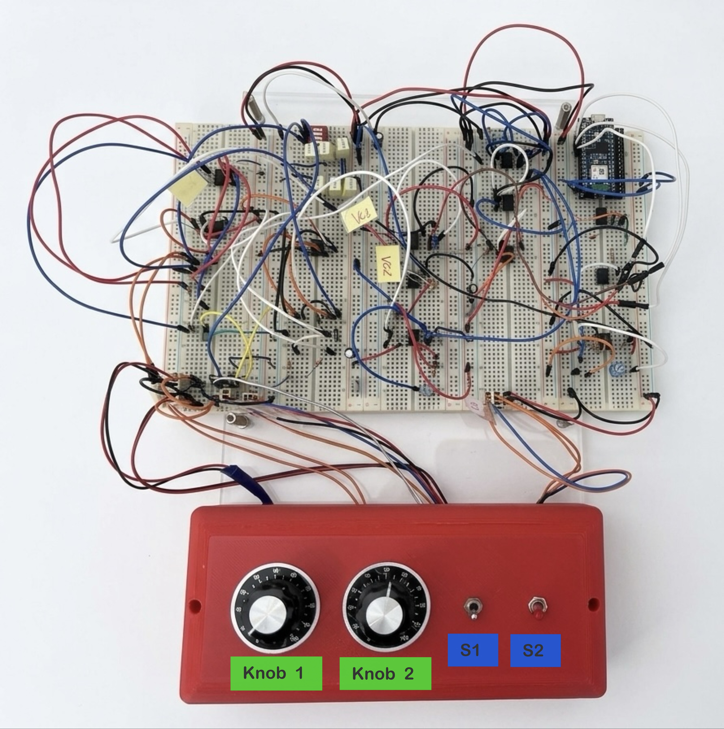
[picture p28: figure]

Figure 1: CHAOS 101 hardware station.

### Control Interface

- Knobs 1 & 2: Potentiometers to vary resistance and modify the output.
- Switch 1: Master switch for the dual 9V battery supply.
- Switch 2: Activates the ESP32 for 10 kHz sampling.

## 3. Activity: The First Flight

### How to power the sistem?

1. Connect the hardware via the USB-C input.
2. Toggle Switch 1 to power the circuit via batteries.
3. Toggle Switch 2 to power the ESP32 and enable the 5V data link.

1 · github.com/jackanfossi/Chaos101

CHAOS 101 — Activity Guide | Grenoble INP-Phelma · MSc Nanotechnologies

## 4. Web interface

Thanks to the onboard Wi-Fi powered by the Arduino-compatible ESP32, the CHAOS 101 interface is now live and accessible to everyone. Simply connect your own device to our web portal to explore the ’order within disorder’ in real-time.

### 3D phase space

1. Turn Knob 2 three full rotations to set the system’s equilibrium point.
2. Observe the periodic regime, which appears on the display as a stable elliptical trajectory.
3. Slowly rotate Knob 1 until the trajectories begin to intersect and diverge.
4. Continue adjusting until the Double-Scroll attractor forms—you have now generated real chaos.

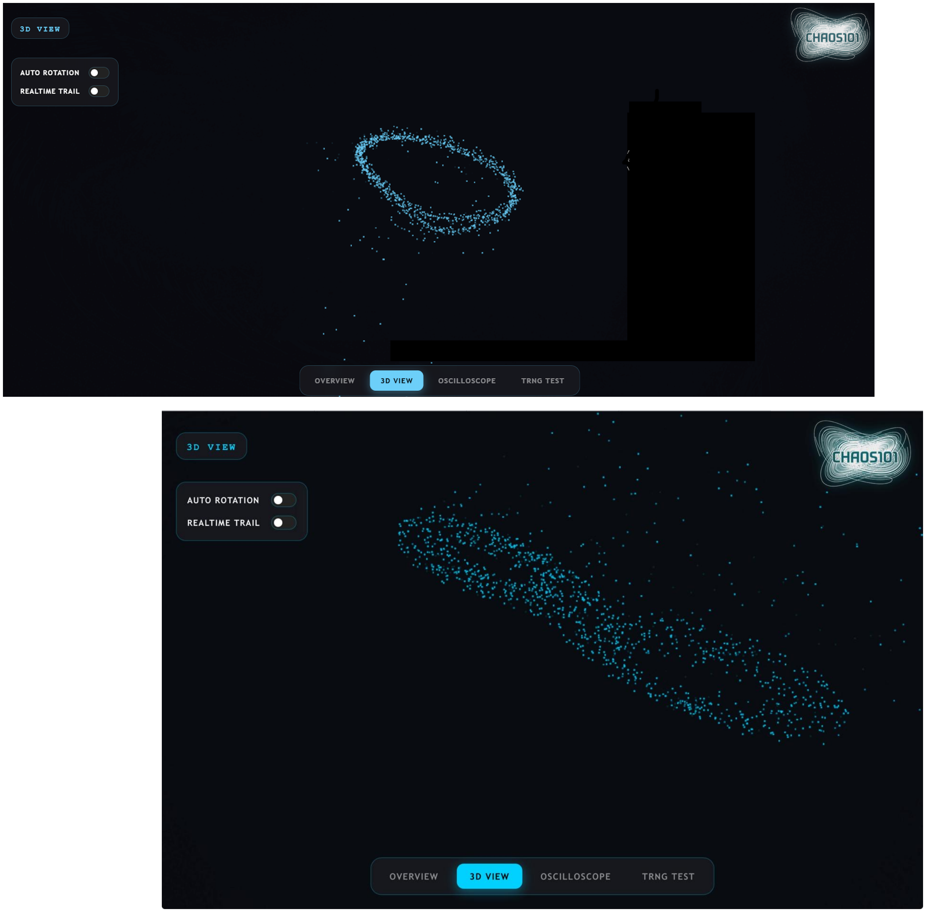
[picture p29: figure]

### Live oscilloscope

1. Real-Time State Monitoring: Monitor the circuit’s core state variables (V1, V2, and IL) directly in the time domain.
2. Chaotic Fluctuations: Witness unpredictable signals that never repeat the same pattern, illustrating the system’s extreme sensitivity.

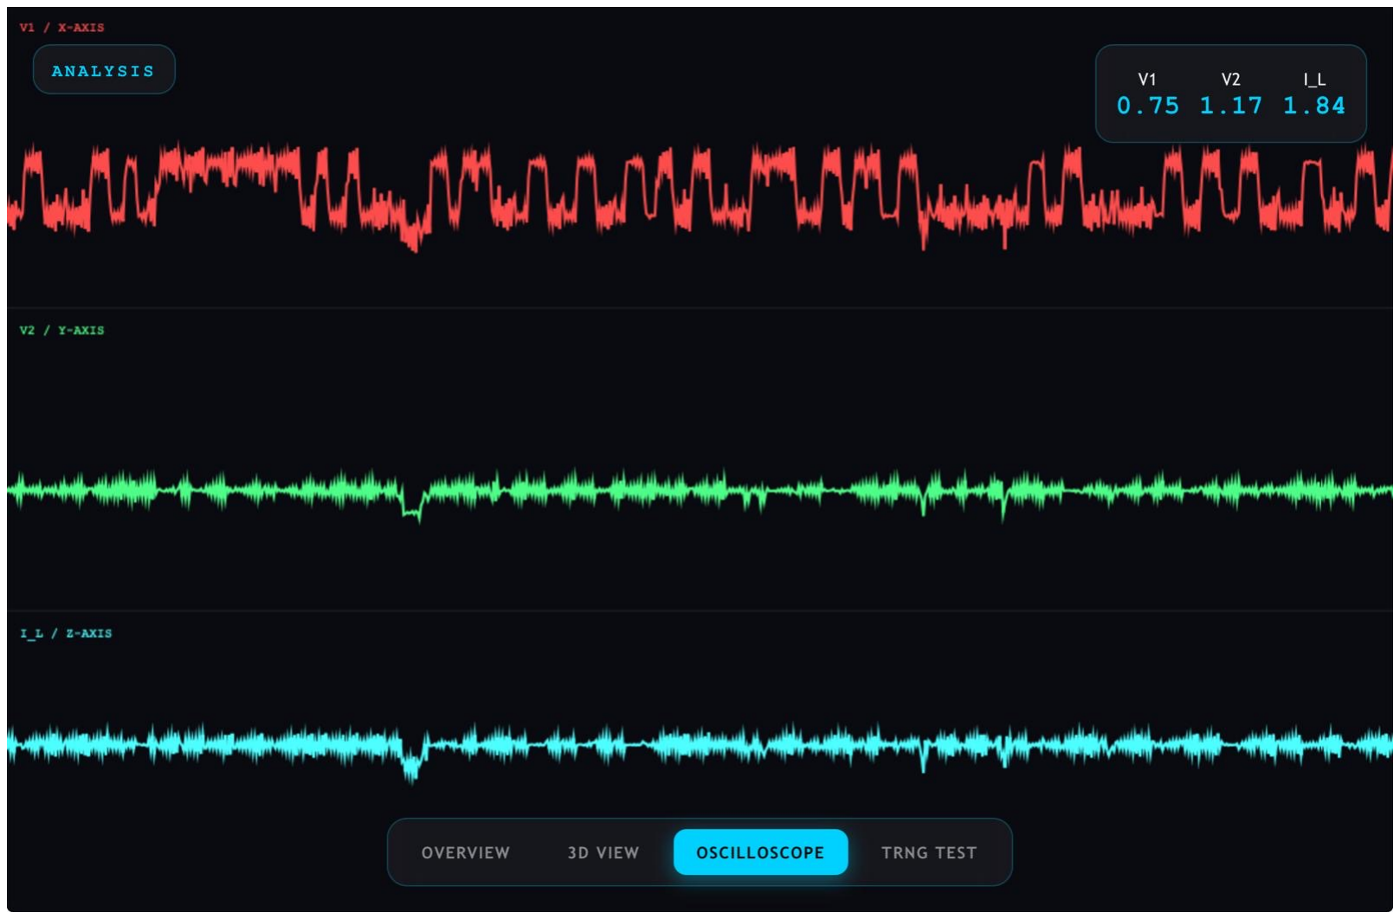
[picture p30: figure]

### TRNG

1. Analyze the TRNG Plots: Observe and interpret the generated visual plots to understand the source behavior.
2. Monte Carlo Plot: Verify the geometric randomness via the π estimation (3.168223), checking that the error remains below 1%.
3. Bitmap & Entropy: Analyze the spatial independence on the Noise Bitmap and verify that the entropy is near the ideal maximum (7.998205 bits/byte).

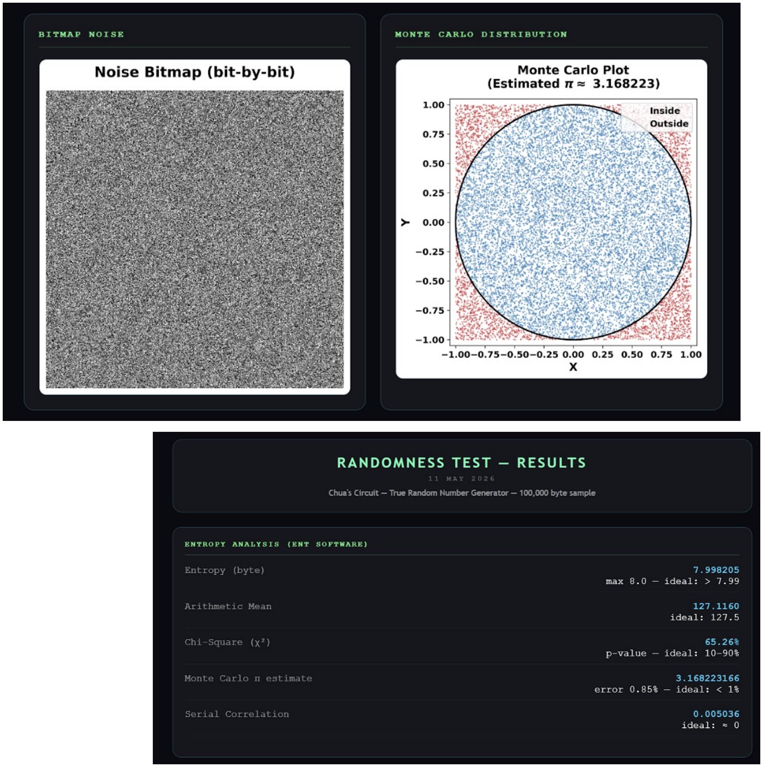
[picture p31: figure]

2 · github.com/jackanfossi/Chaos101

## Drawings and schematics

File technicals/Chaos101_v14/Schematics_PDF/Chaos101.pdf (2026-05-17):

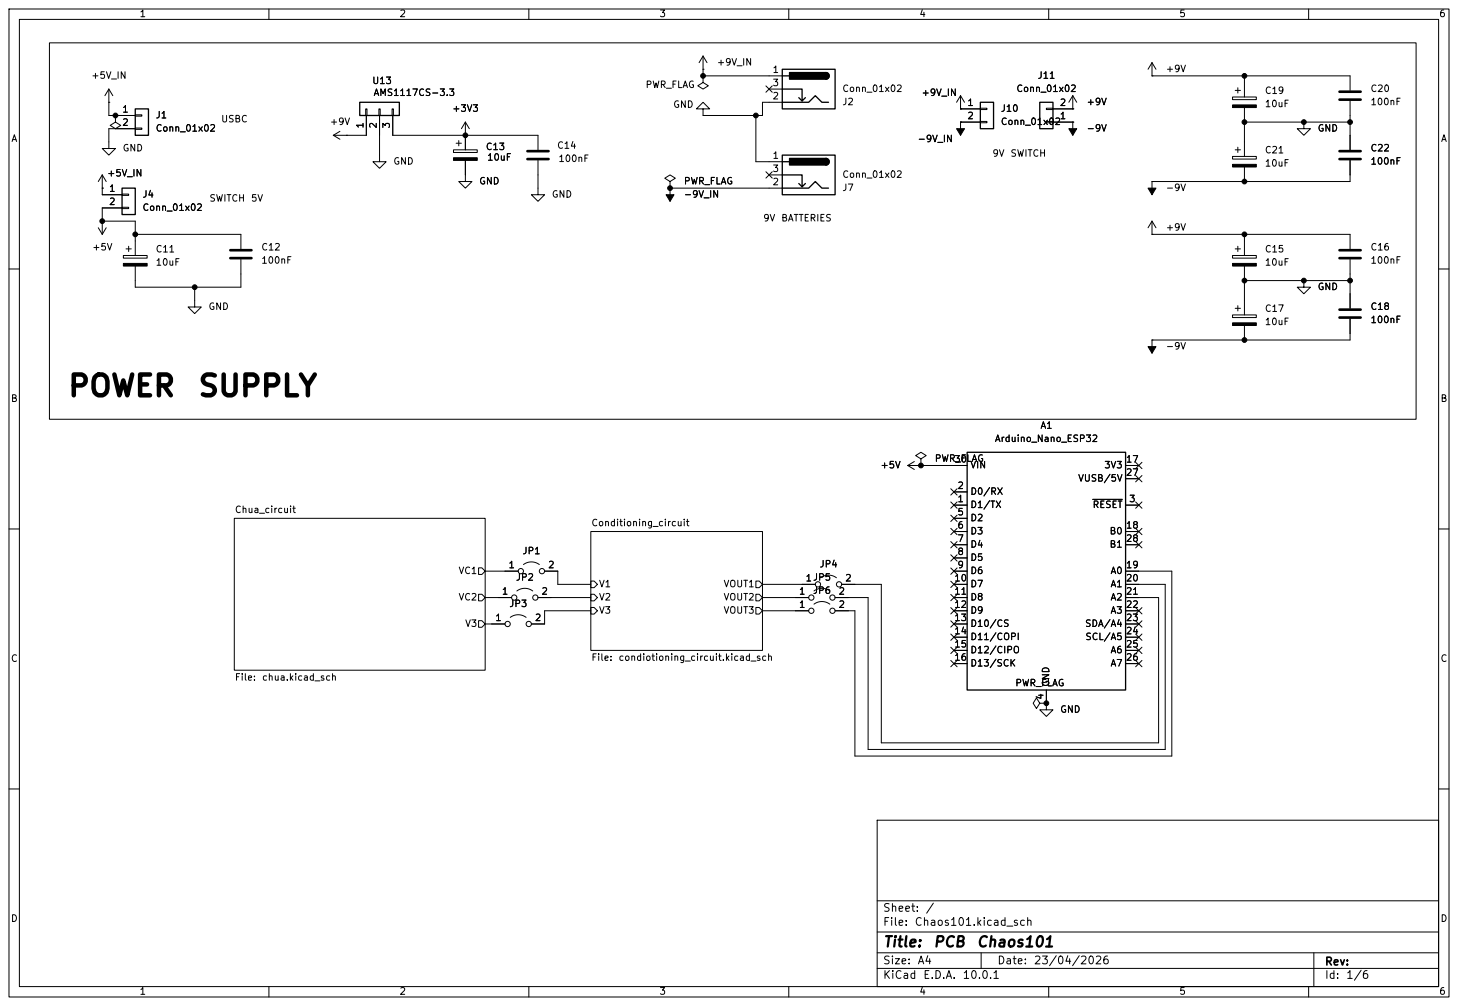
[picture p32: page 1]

9V BATTERIES USBC POWER SUPPLY

4 D2 5 D3 6 D4 7 D5 8 D6 9 D7 10 D8 11 D9 12 D10/CS 13 D11/COPI 14 D12/CIPO 15 D13/SCK 16

Size: A4 | Rev:
KiCad E.D.A. 10.0.1 | Id: 1/6

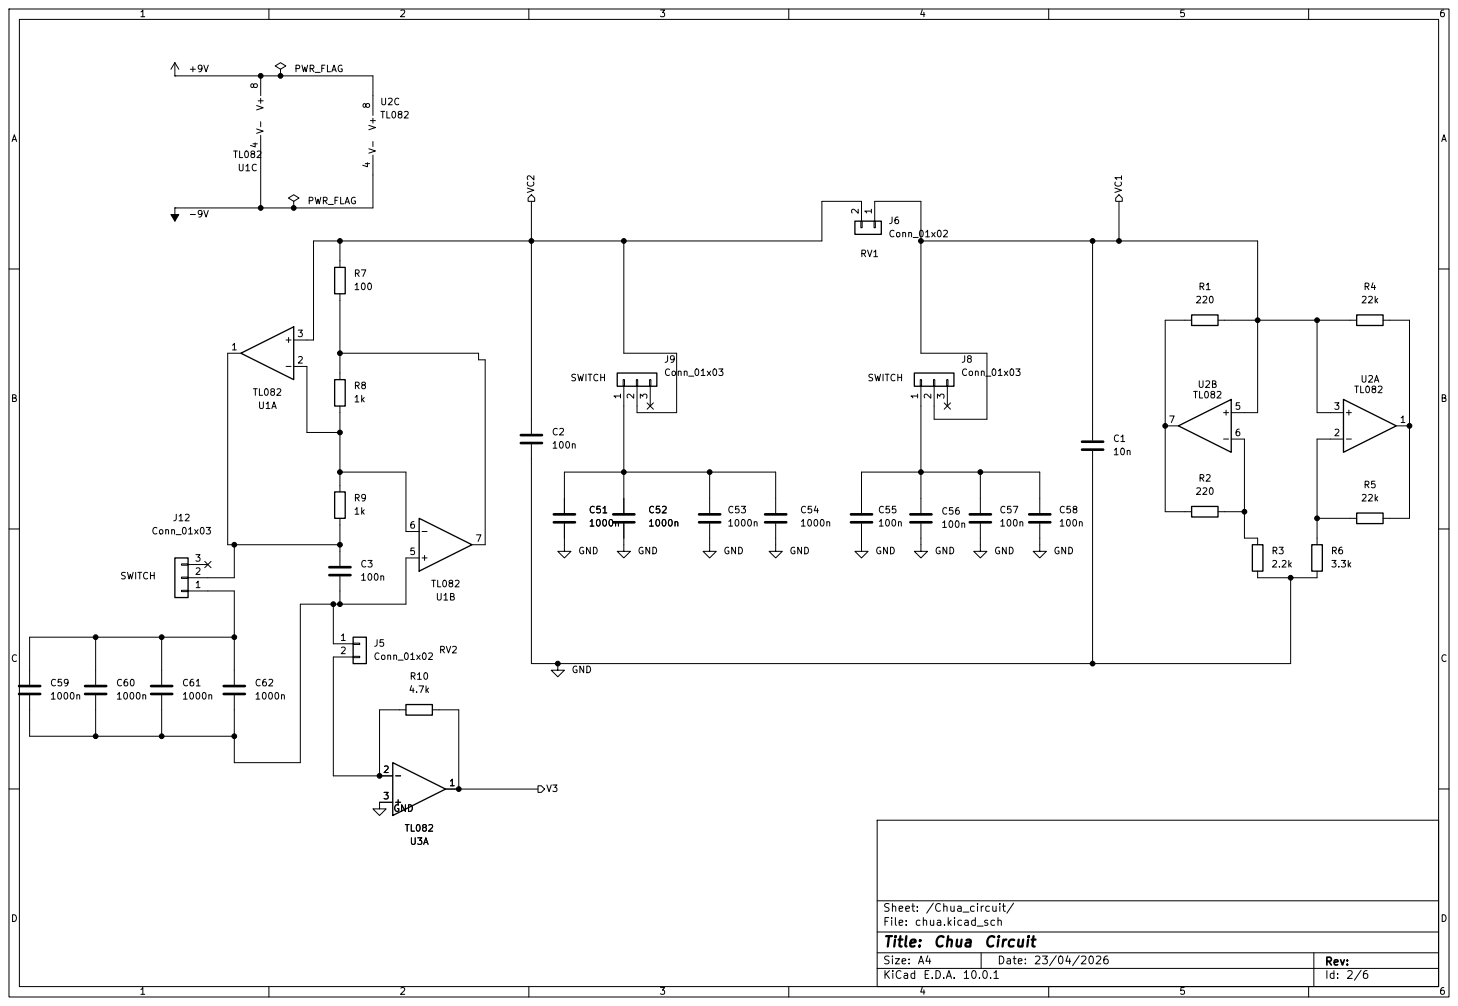
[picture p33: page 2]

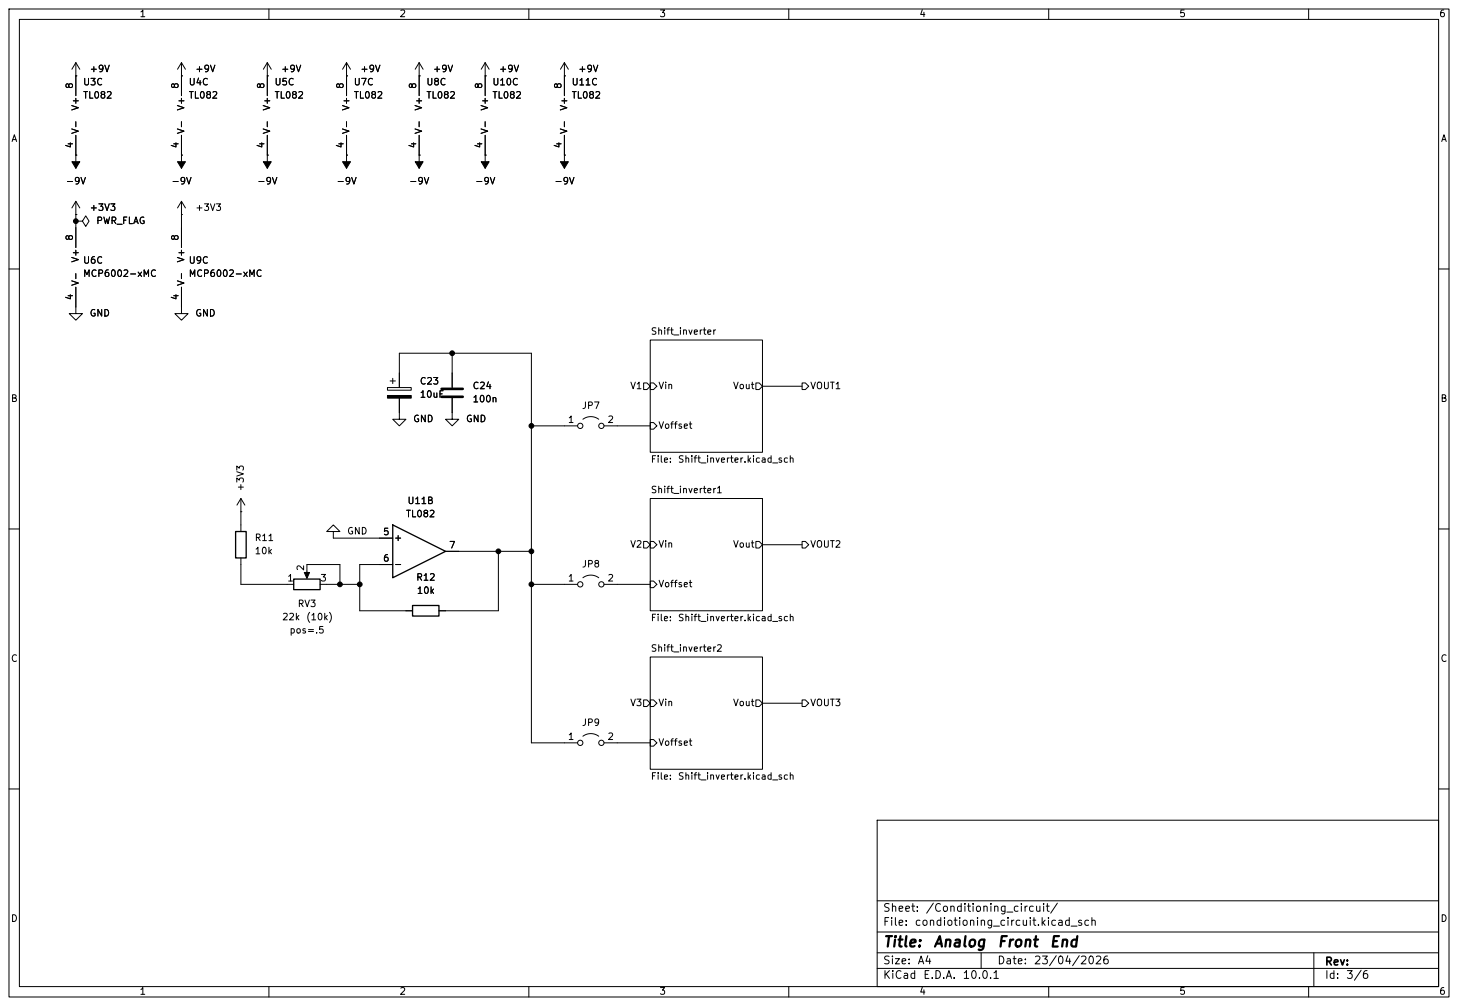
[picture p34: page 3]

Sheet: /Conditioning_circuit/
File: condiotioning_circuit.kicad_sch
Title: Analog Front End

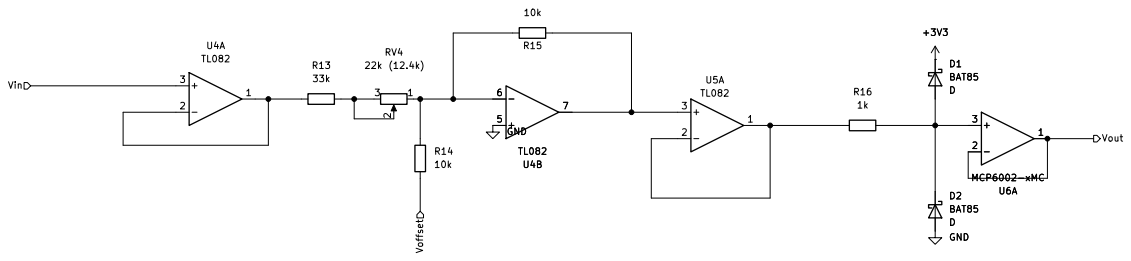
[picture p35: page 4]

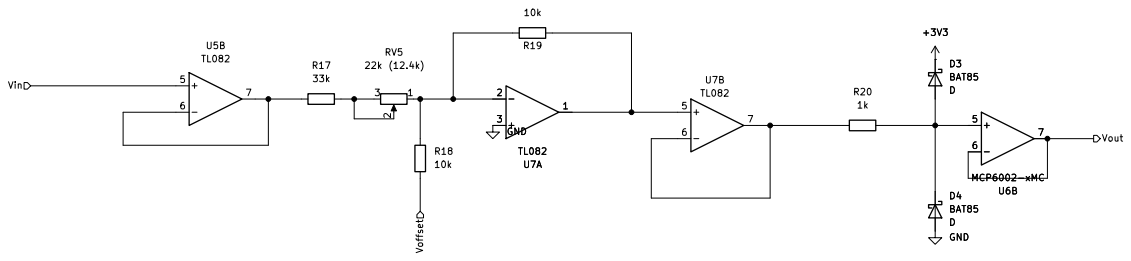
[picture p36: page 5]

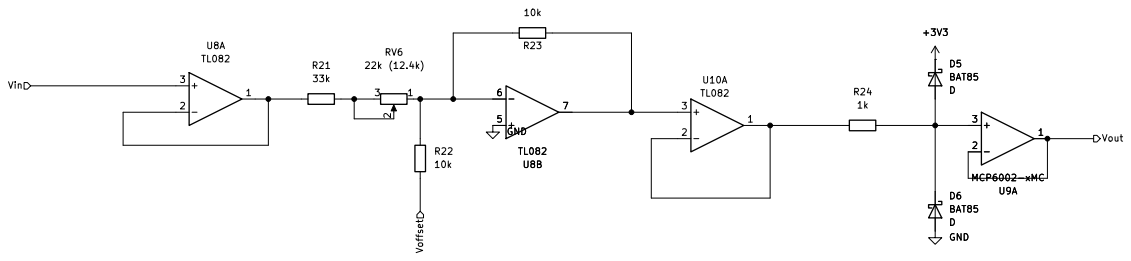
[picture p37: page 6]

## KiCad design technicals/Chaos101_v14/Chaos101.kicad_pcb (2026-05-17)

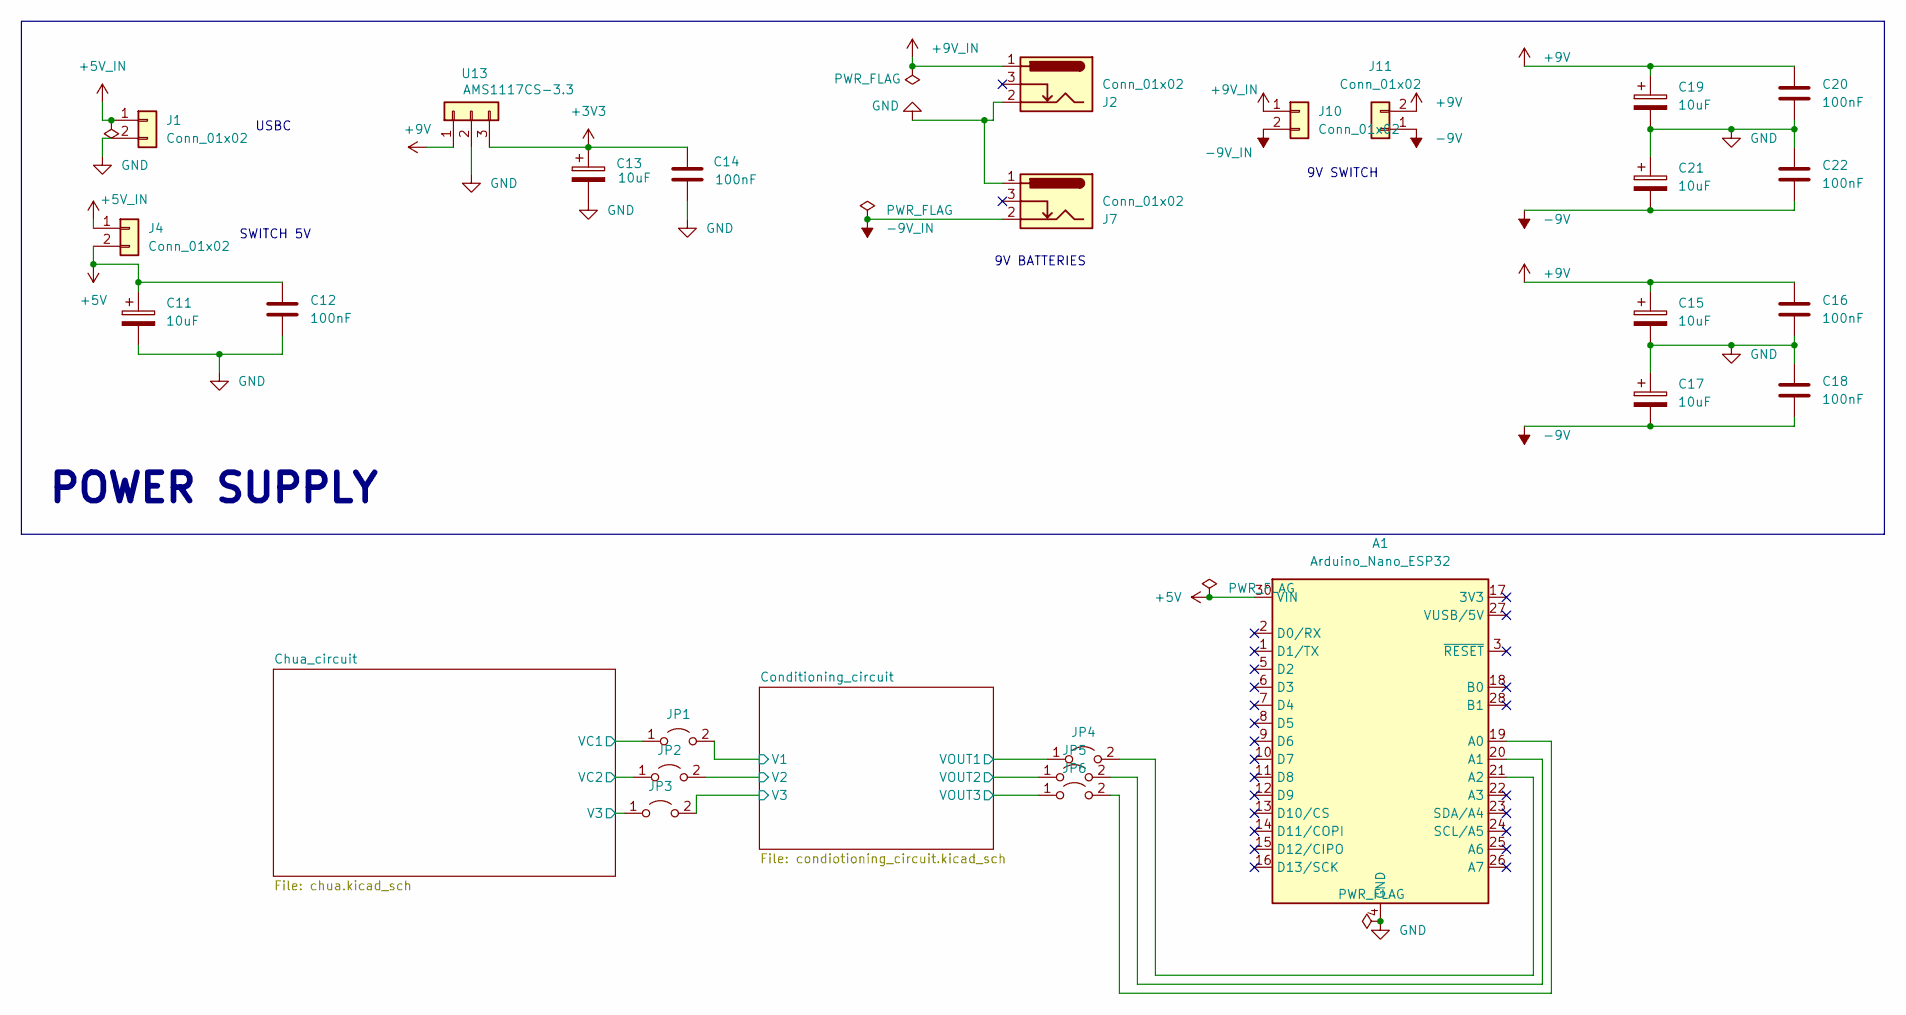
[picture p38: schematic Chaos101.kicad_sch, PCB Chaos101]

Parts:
A1: Arduino_Nano_ESP32; Arduino_Nano
C11, C13, C15, C17, C19, C21: 10uF; CONDENSATEUR_POL_5.08MM
C12, C14, C16, C18, C20, C22: 100nF; CONDENSATEUR_5.08MM
J1, J4, J10, J11: Conn_01x02; PinHeader_1x02_P2.54mm_Vertical
J2, J7: Conn_01x02; BarrelJack_CLIFF_FC681465S_SMT_Horizontal
JP1, JP2, JP3, JP4, JP5, JP6: r=1m; PinHeader_1x02_P2.54mm_Vertical
U13: AMS1117CS-3.3; PinHeader_1x03_P2.54mm_Vertical

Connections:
+3V3: C13.1, C14.1, U13.3; also elsewhere on the board
+5V: A1.30 (VIN), C11.1, C12.1, J4.2
+5V_IN: J1.1, J4.1
+9V: C15.1, C16.1, C19.1, C20.1, J11.2, U13.1; also elsewhere on the board
+9V_IN: J2.1, J10.1
-9V: C17.2, C18.2, C21.2, C22.2, J11.1; also elsewhere on the board
-9V_IN: J7.2, J10.2
/Chua_circuit/V3: JP3.1 (A); also elsewhere on the board
/Chua_circuit/VC1: JP1.1 (A); also elsewhere on the board
/Chua_circuit/VC2: JP2.1 (A); also elsewhere on the board
/Conditioning_circuit/V1: JP1.2 (B); also elsewhere on the board
/Conditioning_circuit/V2: JP2.2 (B); also elsewhere on the board
/Conditioning_circuit/V3: JP3.2 (B); also elsewhere on the board
/Conditioning_circuit/VOUT1: JP4.1 (A); also elsewhere on the board
/Conditioning_circuit/VOUT2: JP5.1 (A); also elsewhere on the board
/Conditioning_circuit/VOUT3: JP6.1 (A); also elsewhere on the board
GND: A1.4 (GND), A1.29 (GND), C11.2, C12.2, C13.2, C14.2, C15.2, C16.2, C17.1, C18.1, C19.2, C20.2, C21.1, C22.1, J1.2, J2.2, J7.1, U13.2; also elsewhere on the board
unnamed: A1.19 (A0), JP6.2 (B)
unnamed: A1.20 (A1), JP5.2 (B)
unnamed: A1.21 (A2), JP4.2 (B)

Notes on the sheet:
9V SWITCH
9V BATTERIES
POWER SUPPLY
USBC
SWITCH 5V

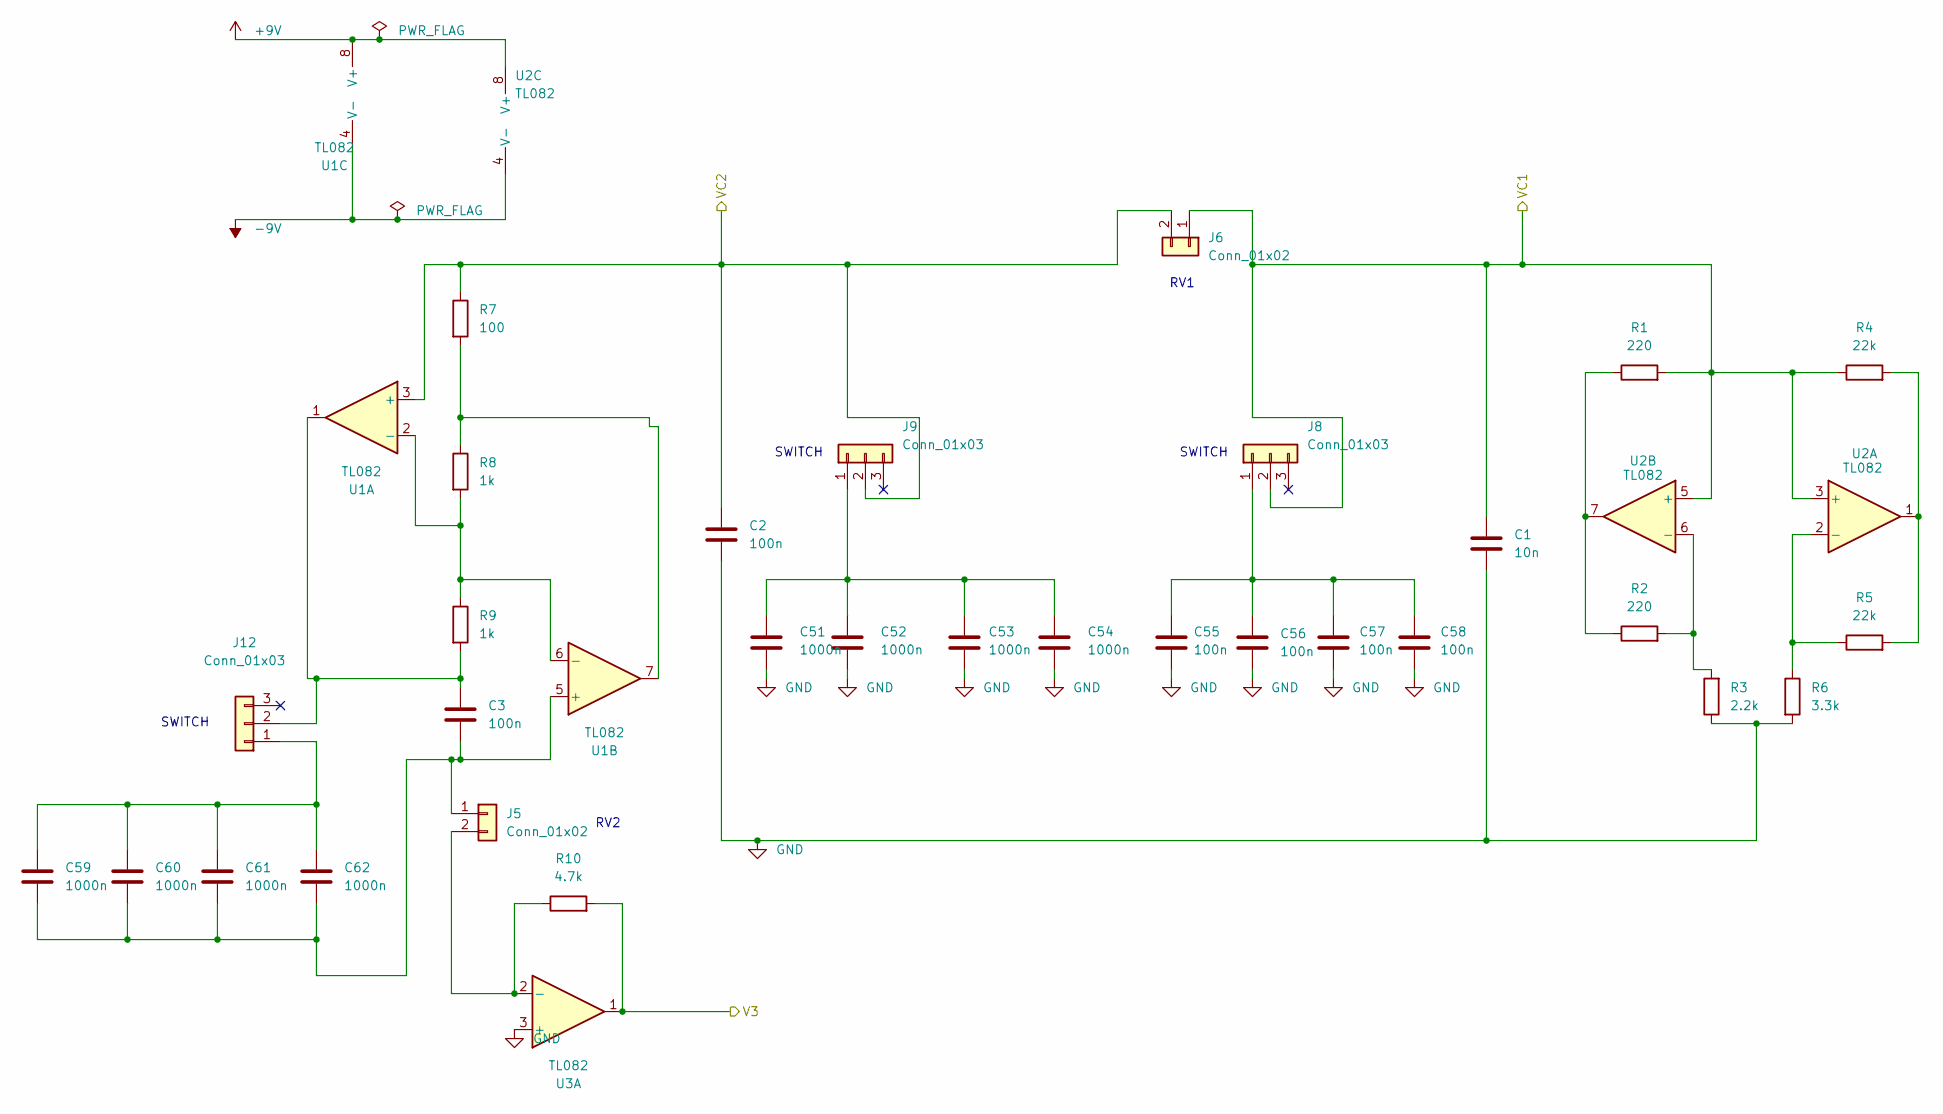
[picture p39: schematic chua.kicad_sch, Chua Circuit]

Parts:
C1: 10n; CONDENSATEUR_5.08MM
C2, C3, C55, C56, C57, C58: 100n; CONDENSATEUR_5.08MM
C51, C52, C53, C54, C59, C60, C61, C62: 1000n; CONDENSATEUR_5.08MM
J5, J6: Conn_01x02; PinHeader_1x02_P2.54mm_Vertical
J8, J9, J12: Conn_01x03; PinHeader_1x03_P2.54mm_Vertical
R1, R2: 220; R_Axial_DIN0207_L6.3mm_D2.5mm_P10.16mm_Horizontal
R3: 2.2k; R_Axial_DIN0207_L6.3mm_D2.5mm_P10.16mm_Horizontal
R4, R5: 22k; R_Axial_DIN0207_L6.3mm_D2.5mm_P10.16mm_Horizontal
R6: 3.3k; R_Axial_DIN0207_L6.3mm_D2.5mm_P10.16mm_Horizontal
R7: 100; R_Axial_DIN0207_L6.3mm_D2.5mm_P10.16mm_Horizontal
R8, R9: 1k; R_Axial_DIN0207_L6.3mm_D2.5mm_P10.16mm_Horizontal
R10: 4.7k; R_Axial_DIN0207_L6.3mm_D2.5mm_P10.16mm_Horizontal
U1, U2, U3: TL082; DIP-8_W7.62mm_Socket_LongPads

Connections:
+9V: U1.8 (V+), U2.8 (V+); also elsewhere on the board
-9V: U1.4 (V-), U2.4 (V-); also elsewhere on the board
/Chua_circuit/V3: R10.2, U3.1; also elsewhere on the board
/Chua_circuit/VC1: C1.1, J6.1, J8.2, R1.2, R4.1, U2.3 (+), U2.5 (+); also elsewhere on the board
/Chua_circuit/VC2: C2.1, J6.2, J9.2, R7.1, U1.3 (+); also elsewhere on the board
GND: C1.2, C2.2, C51.2, C52.2, C53.2, C54.2, C55.2, C56.2, C57.2, C58.2, R3.1, R6.2, U3.3 (+); also elsewhere on the board
unnamed: C3.2, C59.2, C60.2, C61.2, C62.2, J5.1, U1.5 (+)
unnamed: J5.2, R10.1, U3.2 (-)
unnamed: C55.1, C56.1, C57.1, C58.1, J8.1
unnamed: C51.1, C52.1, C53.1, C54.1, J9.1
unnamed: C59.1, C60.1, C61.1, C62.1, J12.1
unnamed: C3.1, J12.2, R9.2, U1.1
unnamed: R1.1, R2.1, U2.7
unnamed: R4.2, R5.2, U2.1
unnamed: R7.2, R8.1, U1.7
unnamed: R8.2, R9.1, U1.2 (-), U1.6 (-)
unnamed: R5.1, R6.1, U2.2 (-)
unnamed: R2.2, R3.2, U2.6 (-)

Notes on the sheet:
RV2
SWITCH
RV1

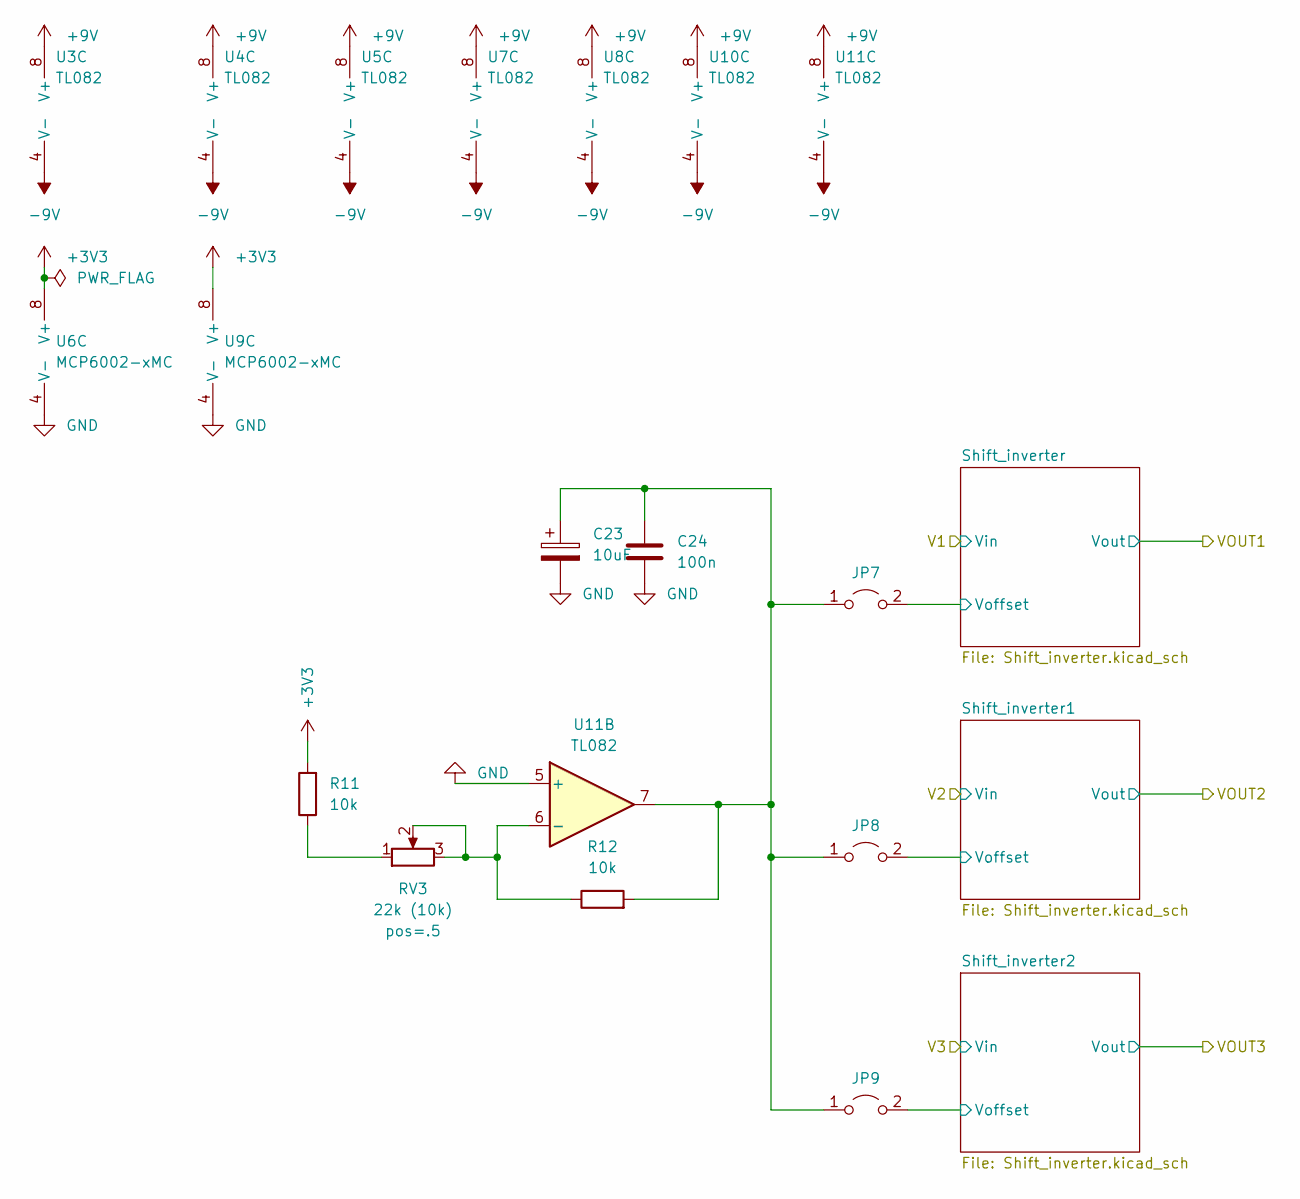
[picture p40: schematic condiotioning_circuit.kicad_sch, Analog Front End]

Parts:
C23: 10uF; CONDENSATEUR_POL_5.08MM
C24: 100n; CONDENSATEUR_5.08MM
JP7, JP8, JP9: r=1m; PinHeader_1x02_P2.54mm_Vertical
R11, R12: 10k; R_Axial_DIN0207_L6.3mm_D2.5mm_P10.16mm_Horizontal
RV3: 22k (10k); Potentiometer_Piher_PT-10-V10_Vertical
U3, U4, U5, U7, U8, U10, U11: TL082; DIP-8_W7.62mm_Socket_LongPads
U6, U9: MCP6002-xMC; DIP-8_W7.62mm_Socket_LongPads

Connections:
+3V3: R11.2, U6.8 (V+), U9.8 (V+); also elsewhere on the board
+9V: U3.8 (V+), U4.8 (V+), U5.8 (V+), U7.8 (V+), U8.8 (V+), U10.8 (V+), U11.8 (V+); also elsewhere on the board
-9V: U3.4 (V-), U4.4 (V-), U5.4 (V-), U7.4 (V-), U8.4 (V-), U10.4 (V-), U11.4 (V-); also elsewhere on the board
/Conditioning_circuit/Shift_inverter1/Voffset: JP8.2 (B); also elsewhere on the board
/Conditioning_circuit/Shift_inverter2/Voffset: JP9.2 (B); also elsewhere on the board
/Conditioning_circuit/Shift_inverter/Voffset: JP7.2 (B); also elsewhere on the board
/Conditioning_circuit/V2: U5.5 (+); also elsewhere on the board
/Conditioning_circuit/VOUT2: U6.6 (-), U6.7; also elsewhere on the board
GND: C23.2, C24.2, U6.4 (V-), U9.4 (V-), U11.5 (+); also elsewhere on the board
unnamed 24: U6.5 (+); also elsewhere on the board
unnamed: C23.1, C24.1, JP7.1 (A), JP8.1 (A), JP9.1 (A), R12.2, U11.7
unnamed: R11.1, RV3.1
unnamed 47: U5.6 (-), U5.7; also elsewhere on the board
unnamed: R12.1, RV3.2, RV3.3, U11.6 (-)

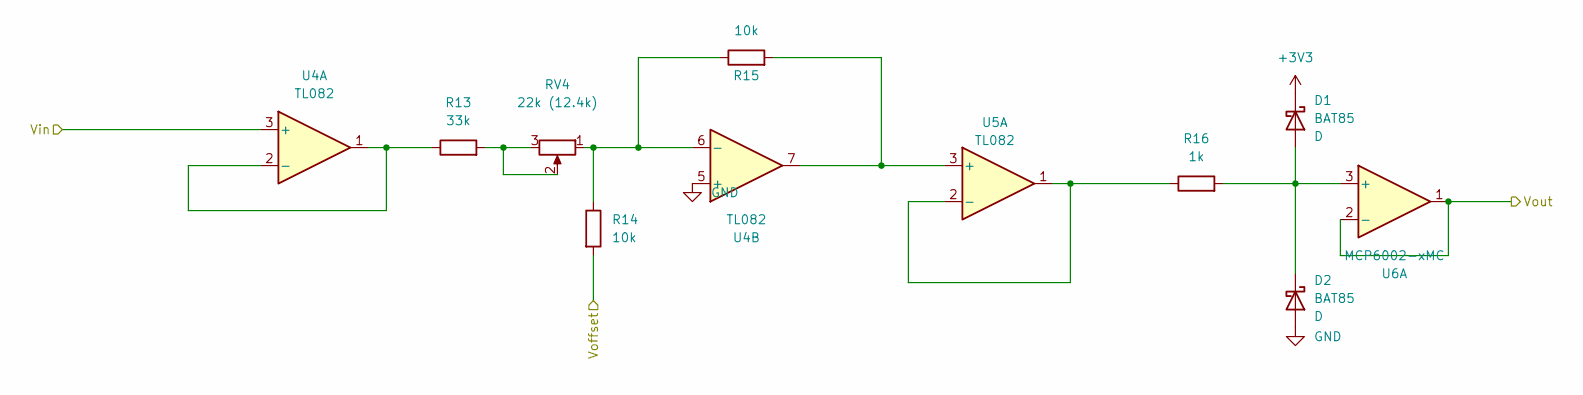
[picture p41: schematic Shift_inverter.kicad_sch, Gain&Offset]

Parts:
D1, D2: BAT85; DIODE_10.16mm
R13: 33k; R_Axial_DIN0207_L6.3mm_D2.5mm_P10.16mm_Horizontal
R14, R15: 10k; R_Axial_DIN0207_L6.3mm_D2.5mm_P10.16mm_Horizontal
R16: 1k; R_Axial_DIN0207_L6.3mm_D2.5mm_P10.16mm_Horizontal
RV4: 22k (12.4k); Potentiometer_Piher_PT-10-V10_Vertical
U4, U5: TL082; DIP-8_W7.62mm_Socket_LongPads
U6: MCP6002-xMC; DIP-8_W7.62mm_Socket_LongPads

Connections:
+3V3: D1.1 (K); also elsewhere on the board
/Conditioning_circuit/Shift_inverter/Voffset: R14.2; also elsewhere on the board
/Conditioning_circuit/V1: U4.3 (+); also elsewhere on the board
/Conditioning_circuit/V2: U5.5 (+); also elsewhere on the board
/Conditioning_circuit/VOUT1: U6.1, U6.2 (-); also elsewhere on the board
/Conditioning_circuit/VOUT2: U6.6 (-), U6.7; also elsewhere on the board
GND: D2.2 (A), U4.5 (+); also elsewhere on the board
unnamed: D1.2 (A), D2.1 (K), R16.2, U6.3 (+)
unnamed 24: U6.5 (+); also elsewhere on the board
unnamed: R13.2, RV4.2, RV4.3
unnamed: R13.1, U4.1, U4.2 (-)
unnamed: R14.1, R15.1, RV4.1, U4.6 (-)
unnamed: R15.2, U4.7, U5.3 (+)
unnamed: R16.1, U5.1, U5.2 (-)
unnamed 47: U5.6 (-), U5.7; also elsewhere on the board

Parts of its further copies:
D3, D4, D5, D6: BAT85; DIODE_10.16mm
R17, R21: 33k; R_Axial_DIN0207_L6.3mm_D2.5mm_P10.16mm_Horizontal
R18, R19, R22, R23: 10k; R_Axial_DIN0207_L6.3mm_D2.5mm_P10.16mm_Horizontal
R20, R24: 1k; R_Axial_DIN0207_L6.3mm_D2.5mm_P10.16mm_Horizontal
RV5, RV6: 22k (12.4k); Potentiometer_Piher_PT-10-V10_Vertical

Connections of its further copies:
+3V3: D3.1 (K), D5.1 (K); also elsewhere on the board
/Conditioning_circuit/Shift_inverter1/Voffset: R18.2; also elsewhere on the board
/Conditioning_circuit/Shift_inverter2/Voffset: R22.2; also elsewhere on the board
GND: D4.2 (A), D6.2 (A); also elsewhere on the board
unnamed 24: D3.2 (A), D4.1 (K), R20.2; also elsewhere on the board
unnamed 25: D5.2 (A), D6.1 (K), R24.2; also elsewhere on the board
unnamed: R17.2, RV5.2, RV5.3
unnamed: R21.2, RV6.2, RV6.3
unnamed 47: R17.1; also elsewhere on the board
unnamed 48: R18.1, R19.1, RV5.1; also elsewhere on the board
unnamed 49: R19.2; also elsewhere on the board
unnamed 50: R20.1; also elsewhere on the board
unnamed 51: R21.1; also elsewhere on the board
unnamed 52: R22.1, R23.1, RV6.1; also elsewhere on the board
unnamed 53: R23.2; also elsewhere on the board
unnamed 54: R24.1; also elsewhere on the board

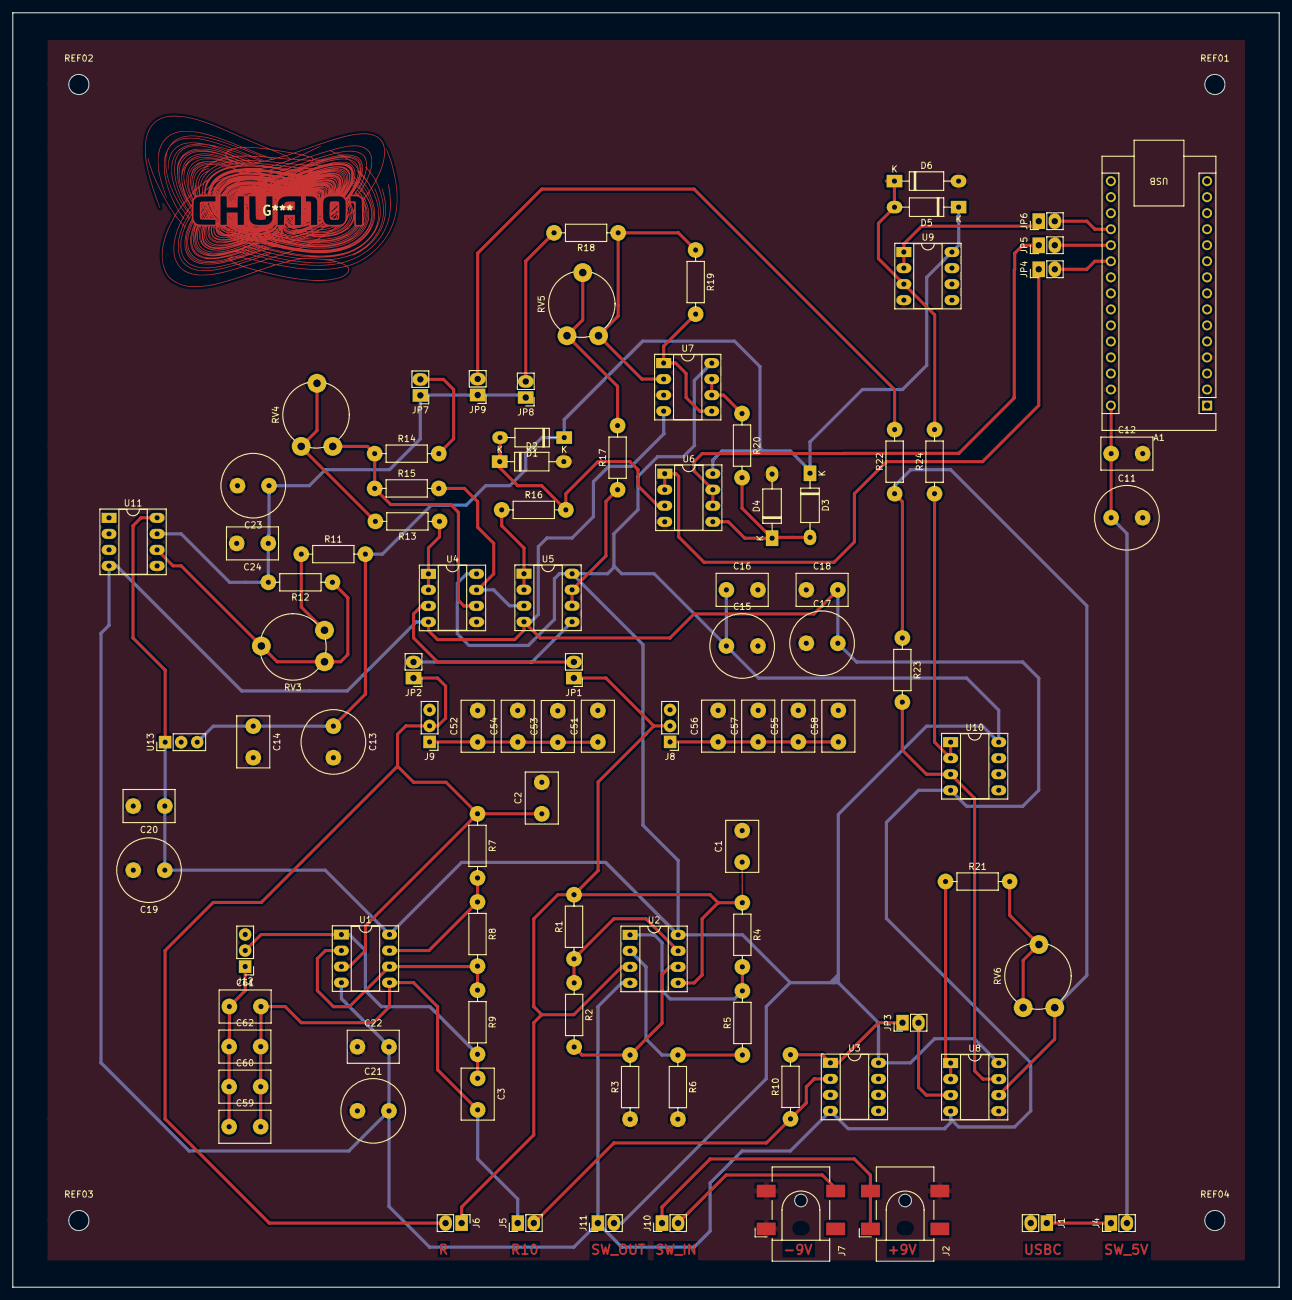
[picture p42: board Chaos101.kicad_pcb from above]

Board: 2 copper layers, 200.7 x 201.9 mm, 100 parts (0 on the bottom side), 56 nets.

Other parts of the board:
REF01, REF02, REF03, REF04: MountingHole_3.2mm_M3

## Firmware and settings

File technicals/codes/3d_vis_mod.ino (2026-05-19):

#include <WiFi.h>
#include <AsyncTCP.h>
#include <ESPAsyncWebServer.h>
#include "webnew_fin.h"

const char* ssid = "CHAOS101";
const char* password = "chaos101";

AsyncWebServer server(80);
AsyncWebSocket ws("/ws");

const int numPoints = 180;
uint16_t visualBuffer[numPoints * 3];

byte currentByte = 0;
int bitCount = 0;

void processTRNG(int valX) {
    static int lastBit = -1;
    int bit = (valX & 1);
    if (lastBit == -1) { lastBit = bit; return; }
    if (bit != lastBit) {
        currentByte = (currentByte << 1) | lastBit;
        if (++bitCount == 8) {
            ws.textAll(String(currentByte));
            bitCount = 0;
            currentByte = 0;
        }
    }
    lastBit = -1;
}

void setup() {
    Serial.begin(115200);
    analogReadResolution(12);

    WiFi.softAP(ssid, password);
    delay(100);

    Serial.print("IP: ");
    Serial.println(WiFi.softAPIP());

    server.on("/", HTTP_GET, [](AsyncWebServerRequest* request) {
        request->send(200, "text/html", webnew_fin);
    });

    server.addHandler(&ws);
    server.begin();
}

void loop() {
    // Nessun availableForWriteAll() - era quello che bloccava su Windows/Android
    if (ws.count() > 0) {
        for (int i = 0; i < numPoints; i++) {
            uint16_t x = analogRead(A0);
            uint16_t y = analogRead(A1);
            uint16_t z = analogRead(A2);

            visualBuffer[i * 3]     = x;
            visualBuffer[i * 3 + 1] = y;
            visualBuffer[i * 3 + 2] = z;

            if (i % 5 == 0) processTRNG(x);
        }
        ws.binaryAll((uint8_t*)visualBuffer, sizeof(visualBuffer));
    }

    ws.cleanupClients();
    delay(10);
}
